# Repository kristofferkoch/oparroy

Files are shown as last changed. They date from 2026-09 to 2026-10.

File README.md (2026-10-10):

# oparroy

A read+write, fault-tolerant ring communication protocol for **extremely
cheap** microcontroller nodes, inspired by the WS2812 single-wire
protocol.

Unlike WS2812's write-only daisy chain, oparroy closes the chain into a
ring so nodes can both send and receive. The physical layer is designed
so that **no single point of failure** — a broken connector (permanent
or intermittent), or a dead/hung microcontroller — partitions the ring:

- The ring is dual: every segment carries two counter-rotating data
  rings with symmetric rebroadcast, so any single fault leaves every
  node reachable ([DESIGN.md §3](DESIGN.md#3-ring-topology-and-bypass)).
- Bypass wiring routes around failed interconnects.
- Each node has a semi-passive hardware watchdog that bypasses the
  node's RX→TX path unless the MCU actively keeps the bypass disabled.
- Status LEDs make faults visually locatable to node and segment
  without instruments.

**Extremely low node cost is the central design principle** (sub-3-NOK
MCU class); every other driver — resilience, repairability,
testability — is achieved subject to it. Supervisor and test
infrastructure, by contrast, may cost freely.

## Hardware direction

- **Node MCU: CH32V003F4P6** — 48 MHz
  RV32EC in TSSOP-20, on-chip comparator routable to timer capture,
  ~$0.14 @4k. Clocked from the factory-trimmed internal HSI — no
  crystal; the ratio-metric PHY makes absolute clock accuracy
  irrelevant. Rationale:
  [docs/mcu-research.md](docs/mcu-research.md);
  extracted part facts: `datasheets/CH32V003/notes/`.
- **Supervisor: RP2040** — its PIO is the re-timing PHY engine and
  golden-reference transceiver; on the test board its PIO also runs as
  a logic analyzer on the instrumented boundary node ([DESIGN.md §6](DESIGN.md#6-test-board)).
- **PHY**: WS2812-compatible duty-coded
  PWM cells with ratio-metric decode at an 800 kbit/s anchor,
  comparator RX + DMA, per-bit cut-through re-timing, positional
  addressing, and the frame gap as a ring-wide vsync latch
  ([DESIGN.md §2](DESIGN.md#2-physical-layer); analysis:
  [docs/phy-analysis.md](docs/phy-analysis.md)).
- **Segment interconnect** ([DESIGN.md §2.1](DESIGN.md#21-ring-power-rail), [§3](DESIGN.md#3-ring-topology-and-bypass)): 2x5-pin IDC
  connectors (2.54 mm box headers on 3M 3365/10 ribbon) carry both
  counter-rotating data rings plus power — a single 3.3 V
  rail that is both the signaling rail and node power, and a raw
  5–18 V rail for payloads with their own buck. On 3M 3365 ribbon,
  segments reach **10 m unamplified**; the 470 Ω TX series resistor,
  not the cable, sets the limit (simulation:
  [docs/cable-reach.md](docs/cable-reach.md)).
- **Node I/O**: potmeter, buttons/matrix, capacitive touch, I2C
  accelerometer, LEDs, buzzer — nodes are smart peripherals serving
  cooked data (Bela/Trill pattern, see
  [docs/bela-lessons.md](docs/bela-lessons.md)).
- **Test board**: 8 ring nodes + supervisor, full fault injection
  (per-segment open/short, per-node power cut, keep-alive cut), everything
  scriptable for hands-off hardware-in-the-loop testing. Doubles as
  the **demonstrator**: some nodes carry human-facing I/O
  (potentiometer, buttons, LEDs, buzzer), each input overridable by
  the supervisor so scripted runs stay hands-off ([DESIGN.md §6](DESIGN.md#6-test-board)).
  4-layer, self-documenting silkscreen. Prototypes assembled by
  **JLCPCB Economic PCBA**; part
  selection is inventory-driven — minimize unique Extended BOM lines.

## Firmware direction

- **Freestanding C++, no standard library** — RAII, placement `new` on
  memory-mapped I/O, `constexpr` config; no exceptions/RTTI/heap.
- Foundation library modeled on **SerenityOS's AK**, landed in
  `firmware/lib/`: `ErrorOr<T>` with `TRY` propagation and fallible
  `try_*` APIs, `VERIFY` with a target failure hook, fixed-capacity
  `StaticVector`/`Span`, and a `StaticArena` slot pool.
- **Ring protocol core** in `firmware/protocol/` — bit cells and
  node/ring forwarding logic ([DESIGN.md §2](DESIGN.md#2-physical-layer)) — proven by **KLEE**
  symbolic-execution harnesses and **libFuzzer** harnesses whose seed
  corpora double as the meson test suite; branch coverage is measured
  on the release build (`scripts/coverage-release`).
- The node pin map is captured in the DSL — 17 of 18 CH32V003 GPIO
  assigned with a budget check — and emits `firmware/node/pins.hpp`
  directly ([DESIGN.md §7](DESIGN.md#7-design-capture-dsl)).
- All of it under the project-owned coding standard:
  [code-std.md](code-std.md) holds the language-independent rules and
  links the per-language standards
  ([code-std-cpp.md](code-std-cpp.md),
  [code-std-python.md](code-std-python.md)) — borrowing from
  JSF AV / MISRA / AUTOSAR / CERT, statically checked
  from the first commit ([DESIGN.md §8](DESIGN.md#8-verification-strategy)).

## Tooling

- **Design capture is code**: the home-rolled Python DSL
  (`src/oparroy/dsl/`, [DESIGN.md §7](DESIGN.md#7-design-capture-dsl)) is the single source of truth —
  an IR with subcircuit composition (ports, port arrays, bundles,
  multipacking, component sockets), a validation pass (limit ranges,
  interval containment, waivers as data), and emitters for KiCad
  netlists, ngspice simulation netlists, and firmware pin headers.
  Footprint assignment and annotation/back-annotation are explicit,
  repeatable stages between capture and pcbnew, so emission is not a
  one-shot export. The parts DB carries assembler-stock status
  (inventory-driven selection), and a `.kicad_pcb` layout property
  checker audits the physical layout (stackup, trace budgets,
  bypass-path copper independence, mechanical contracts). KiCad is
  used for layout only. Learn the DSL from
  [docs/dsl-tutorial.md](docs/dsl-tutorial.md); the API map is
  [docs/dsl-reference.md](docs/dsl-reference.md). Circuit captures live
  in `design/` — the full
  node board is captured (CH32V003 + PHY front-end + charge-pump
  watchdog + status LEDs + segment connectors) — with ngspice benches
  in `circuits/` run via `scripts/sim-run`.
- **Datasheets are extracted, not just stored**: `datasheets/<PART>/`
  holds vendor PDFs plus LLM-readable markdown sidecars (facts,
  per-peripheral notes, quirks) — see `datasheets/README.md`.
- **Meson + ninja** build the firmware ([DESIGN.md §8](DESIGN.md#8-verification-strategy)): one build
  dir per toolchain, freestanding flag set in `meson.build`.
  - host (clang; host objects + LLVM bitcode for KLEE):
    `meson setup build/host --native-file meson/native/clang.ini`
  - CH32V003 (RV32EC objects):
    `meson setup build/rv32ec --cross-file meson/cross/rv32ec.ini`
  - then `meson compile -C build/<dir>`; the reproducibility gate
    `ninja -C build/host check-reproducible` builds every
    configuration twice and compares artifact hashes.
- **nix flake** provides everything non-Python (riscv/arm cross GCC,
  clang 19 + KLEE, AFL++, ngspice, KiCad, uv itself), pinned by
  `flake.lock` — `nix develop` enters the shell (`.envrc` provided for
  direnv users); **uv** owns Python alone (3.14, ruff strict, ty,
  pytest): `uv sync`, then `uv run pytest` / `uv run ruff check` /
  `uv run ty check`.
- **Pre-commit hooks** (`pre-commit install`): clang-format,
  clang-tidy (replaying the host build's `compile_commands.json`), and
  the markdown pipeline
  (mdformat + markdownlint-cli2 + lychee link checks) — cheap checks
  only, ~2 s warm. Hooks are `language: system` against the
  nix-pinned tools, so the flake stays the single tool source.
- **CI** (`.github/workflows/ci.yml`): GitHub Actions runs every gate
  — pytest, firmware host build + unit tests, KLEE proofs, bounded
  fuzz runs, ngspice benches, the rv32ec cross build, the
  reproducibility gate, and the pre-commit suite — inside the nix dev
  shell, so CI exercises byte-identical tools to a laptop.

## Repository layout

| Path | Contents |
| --- | --- |
| `AGENTS.md` | Doc-split and writing conventions for agents |
| `IDEAS.md` | Not-yet-planned ideas (append-only stash) |
| `DESIGN.md` | Settled design decisions + open design questions |
| `KANBAN.md` | Single home for planned work (cards, Next/Backlog) |
| `code-std.md` | Project-owned coding standard: general rules (living) |
| `code-std-cpp.md` | C++ coding standard (living) |
| `code-std-python.md` | Python (DSL) coding standard (living) |
| `README.md` | This file |
| `flake.nix` + `flake.lock` | Pinned dev shell: all non-Python tools ([DESIGN.md §8](DESIGN.md#8-verification-strategy)) |
| `pyproject.toml` + `uv.lock` | Python side: the DSL package (ruff strict, ty, pytest) |
| `src/oparroy/` | Design-capture DSL package (`dsl/`: IR, checks, emitters) |
| `design/` | DSL circuit captures: node board, pin map, parts DB seed |
| `circuits/` | ngspice benches: PHY segment, watchdog, cable reach |
| `tests/` | Python tests (pytest) + golden netlists, `.kicad_pcb` fixtures |
| `meson.build` + `meson/` | Firmware build: flag set, native/cross toolchain files |
| `.envrc` | direnv hook into the flake shell |
| `.pre-commit-config.yaml` | Hook wiring; tools nix-pinned, `language: system` |
| `.github/workflows/` | CI: every gate inside the nix shell |
| `firmware/` | Node/supervisor firmware: foundation lib, ring protocol |
| `scripts/` | Build, sim/proof/fuzz, coverage + pre-commit scripts (sh) |
| `docs/` | Reference documents (research reports, sub-designs); [dsl-tutorial.md](docs/dsl-tutorial.md) + [dsl-reference.md](docs/dsl-reference.md) document the DSL |
| `datasheets/` | Vendor PDFs + extracted markdown sidecars per part |
| `LICENSE` | MIT, copyright 2026 Kristoffer Koch |

Doc conventions follow the IDEAS → KANBAN/DESIGN graduation model:
stray thoughts live in IDEAS.md, planned work in KANBAN.md cards,
settled decisions in DESIGN.md. See
[AGENTS.md §Documentation](AGENTS.md#documentation--the-ideas--kanban--design-split).

## Status

The design-automation pipeline is landed end-to-end: the DSL captures
the full node board, validates it, and emits KiCad and ngspice
netlists, the firmware pin header, and layout constraint skeletons;
simulation benches cover the PHY, the charge-pump watchdog, and cable
reach. On the firmware side the foundation library and the
ring-protocol core are in place under KLEE/fuzz/coverage verification,
and CI runs every gate. No boards exist yet: next up is KiCad layout
of the node board, which unblocks the 8-node test board and the
long-cable bench work. Current work is tracked as cards
in `KANBAN.md`.

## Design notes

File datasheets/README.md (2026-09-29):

# datasheets/

Canonical PDF datasheets and reference manuals for the parts this project
uses, plus LLM-readable sidecar notes. **One directory per part**, e.g.
`datasheets/CH32V003/`:

- `datasheets/<PART>/<PART><doc>-v<ver>.pdf` — the canonical vendor
  documents, version in the filename (e.g.
  `CH32V003/CH32V003DS0-datasheet-v1.8.pdf`).
- `datasheets/<PART>/notes/` — the LLM-readable sidecars. `facts.md` is
  the index and overview (part identity, memory map, electrical quick
  table); each peripheral/topic gets its own file (`opa.md`,
  `timers.md`, `usart-i2c-spi.md`, …) so a task can load only the
  subsystem it touches. `quirks.md` is the errata and tribal-knowledge
  file (issue trackers, wikis, bench findings), one sourced bullet per
  quirk. Facts cite the source document and section (e.g. `(RM §17.2)`).

LLMs read PDFs badly: **read the `notes/` markdown first**; open the PDF
only when the note says the detail wasn't extracted.

## Index

| Part | Role in oparroy | Documents on disk | Notes |
| --- | --- | --- | --- |
| [CH32V003](CH32V003/) | Node MCU — CH32V003F4P6, TSSOP-20 (DESIGN.md §5) | DS0 datasheet v1.8, RM reference manual v1.9, QingKeV2 debug manual v1.0 | [facts](CH32V003/notes/facts.md) + per-peripheral: [opa](CH32V003/notes/opa.md), [timers](CH32V003/notes/timers.md), [dma](CH32V003/notes/dma.md), [adc](CH32V003/notes/adc.md), [gpio-pinout](CH32V003/notes/gpio-pinout.md), [rcc-clocks](CH32V003/notes/rcc-clocks.md), [usart-i2c-spi](CH32V003/notes/usart-i2c-spi.md), [exti-pfic](CH32V003/notes/exti-pfic.md), [sdi-debug](CH32V003/notes/sdi-debug.md), [flash-option-bytes](CH32V003/notes/flash-option-bytes.md), [power-reset](CH32V003/notes/power-reset.md), [quirks](CH32V003/notes/quirks.md) |
| [SN74LVC1G3157](SN74LVC1G3157/) | Ring-A watchdog bypass SPDT analog switch (DESIGN.md §4) | SCES424O (rev. 2025-06) | [facts](SN74LVC1G3157/notes/facts.md) |
| [BAT54S](BAT54S/) | Watchdog charge-pump dual Schottky pair (DESIGN.md §4) | Nexperia BAT54SER v5, TWGMC C727126 | [facts](BAT54S/notes/facts.md) |
| [3M3365](3M3365/) | Candidate segment cable, 28 AWG ribbon (DESIGN.md §3; reach modeling, §9) | 3M TS-0080 v15 | [facts](3M3365/notes/facts.md) |

Not yet vendored: **RP2040** (supervisor MCU, DESIGN.md §5).

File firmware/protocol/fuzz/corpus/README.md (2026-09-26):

# Fuzz seed corpora

Seeds for the libFuzzer harnesses (`firmware/protocol/fuzz/`). Byte
layouts are the harnesses' input grammars — see `fuzz.hpp` for the
event encoding (selector byte `% 5`: 0–2 cell, 3 break, 4 reset; a cell
is selector + period u16 LE + high u16 LE). `scripts/fuzz-run` copies
these into a build-dir work corpus before each run, so the seeds stay
pristine.

## cell/

Raw `(period u16 LE, high u16 LE)` pairs, fed straight to
`decode_cell`.

- `nominal-zero-one` — the two nominal cells (60/19, 60/38 ticks)
- `window-edges` — legality-window boundaries: 43/77 in, 42/78 out,
  high > period
- `tolerance-band` — ±25 % periods (45/60/75) at the 0.32/0.64 ratios

## node/

Prefix: `tele0 tele1 slot_index(u16) slot_bits(u8, mapped to 1+x%16)`,
then events.

- `frame-over-cap` — break, then 2100 nominal cells: past the 2048-bit
  frame cap, the bounded-frame containment case (node.hpp)
- `garbage-cells` — illegal timing, legal cells, break, legal cells
- `reset-mid-frame` — break, cells, brown-out reset, cells, break

## ring/

Prefix: `tele0 tele1 tele2 slot0 slot1 slot2` (slots 0–255, 8 bits
each), then events; a reset event takes one extra node-index byte.

- `three-node-frames` — two clean frames through the chain (echo +
  stamping)
- `faults` — illegal cells, a per-node brown-out, breaks

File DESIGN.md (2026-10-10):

# DESIGN

Settled design decisions, plus §9 for decided-to-be-decided questions
that aren't yet work cards. Sections marked TBD are open.

Settled:

- Project and protocol name: **oparroy**
- License: **MIT**
- Design capture: **home-rolled DSL** (not SKiDL) — owns its IR, emits
  KiCad netlists, constraint checks, firmware headers, simulation netlists
- Test board: **8 ring nodes + 1 supervisor**, **full fault injection**
  (per-segment open/short, per-node power cut, keep-alive cut — all scriptable)
- CI: **local script first** (`test-hw` style target), CI platform
  integration deferred until the board exists
- Firmware language: **freestanding C++ — no standard library**,
  zero-cost abstractions only (RAII, placement new on memory-mapped
  I/O), under an aviation-grade rule set (§8)
- Tool provisioning: **nix flake** for everything non-Python (SDCC/GCC
  toolchains, KLEE/clang, ngspice, KiCad, provers); **uv** for Python
  deps — see §8
- Python tooling: **3.14, uv, ruff (strict), ty, pytest** — package
  scaffold: `src/oparroy/` layout, ruff `ALL` (formatter-conflicts
  off), ty, pytest wired via pre-commit
- MCU: node = **[CH32V003F4P6](datasheets/CH32V003/)** (TSSOP-20),
  supervisor = **RP2040**; toolchains GCC riscv + GCC arm, clang host
  build retained for KLEE (§8)
- Node time base: **internal HSI RC, no crystal** — §5
- PHY: ratio-metric duty-coded PWM, 800 kbit/s anchor, comparator
  RX + DMA, per-bit cut-through re-timing — §2
- Bypass topology: **counter-rotating dual ring, symmetric
  rebroadcast** — RX source select via the OPA's second positive
  input, no per-node parts — §3
- PCBA: prototypes assembled by **JLCPCB** (Economic PCBA); fallback
  for unstocked parts is PCBWay partial-turnkey (§6)
- Firmware build system: **Meson + ninja** — §8
- Ring power rail: **3.3 V, one rail** for signaling and node power;
  regulation is per-payload, never per-node — §2.1

## 1. Overview

oparroy is a single-wire, self-clocked ring protocol inspired by WS2812.
Closing the daisy chain into a ring makes communication bidirectional
(read + write) and provides the substrate for fault tolerance.

Design drivers, in priority order:

1. **Node cost — the central design principle.** Extremely low per-node
   cost outranks every other concern; all other drivers are achieved
   *subject to* it (sub-3-NOK MCU class, minimal external parts). Every
   feature that adds per-node parts or board area must argue for its
   existence against this driver. Note the asymmetry: **supervisor and
   test infrastructure may cost freely** — cost discipline applies to
   the replicated node, not to the one-off tooling around it.
1. **Resilience**: no single connector failure (permanent or intermittent)
   or single MCU failure partitions the ring.
1. **Repairability**: when a fault does occur, it is visually locatable
   to node and segment without instruments (§4.1).
1. **Testability**: hands-off hardware-in-the-loop testing from day one.

## 2. Physical layer

Decided (against the CH32V003's peripherals; full analysis:
[docs/phy-analysis.md](docs/phy-analysis.md)). 800 kbit/s confirmed by
simulation (measured block below); bench confirmation lands with the
test board. Break length is a firmware/timer decision: the analog side
owes only fast, chatter-free settling to idle, which tb_fault shows.

- **Line coding: WS2812-style duty-coded PWM cells with ratio-metric
  decode.** Fixed bit cell, high-then-low; `0` = short high pulse
  (~1/3 cell, T0H ≈ 0.40 µs), `1` = long high pulse (~2/3 cell,
  T1H ≈ 0.80 µs). The spec is the *ratio* — high-time/period against
  the cell midpoint — not absolute times: the coding tolerates ~±25 %
  node-clock error, so HSI-only nodes (±2.2 % worst case, no crystal —
  §5) sit an order of magnitude inside budget. The wire signal stays
  WS2812-compatible, so COTS decoders, test gear, and RP2040 PIO
  reference code work unmodified.
- **Bit rate: 800 kbit/s anchor** (1.25 µs cell = 60 timer ticks at
  48 MHz; capture resolution 20.8 ns). The rate is a free parameter —
  the ceiling is comparator response and cable reach (§9), not the
  timers — but at 800 k the OPA (12 MHz GBW, 7.7 V/µs) is nowhere near
  the bottleneck and COTS WS2812 tooling applies. Frame/latch marker:
  line-low break, ≥ 50 µs baseline (WS2812's reset is the upper
  reference; MCU nodes may go shorter once bench confirms — the
  vsync semantics below ride on the break either way).
- **Signaling: 3.3 V single-ended**, push-pull at VDD per segment,
  idle low. RX threshold = VDD/2 divider on an OPA negative input. The
  OPA has no documented hysteresis: glitch rejection comes from the
  TIM2 input digital filter (ICxF) plus ratio-decode margins, not
  analog feedback. Simulation confirmed this
  (`circuits/phy-segment/tb_noise.cir`): zero spurious rxout edges
  under ringing (lseg ≤ 1 µH × cseg ≤ 470 pF) and under ±250 mV-class
  capacitive crosstalk at ±13 mV comparator offset; worst high-time
  error ~1.2 ns against a ≥ 100 ns decode-margin budget. ICxF fCK_INT
  N=8 is free insurance (its ~167 ns delay is edge-symmetric and
  cancels in the ratio). The feedback-resistor fallback (OPO = PD4)
  stays unpopulated.
- **RX path:** OPA comparator routed *internally* to TIM2 CH1 — no
  GPIO spent on the comparator output. TIM2 PWM-input mode (CH1+CH2
  pair, hardware counter reset) captures per-bit period and high-time;
  DMA channels 5/7 stream captures into an SRAM ring buffer. Per-bit
  ISRs are ruled out: 60 cycles/bit at 800 kbit/s leaves nothing after
  PFIC entry; decode runs per burst, amortized ~10 cycles/bit
  ([opa.md](datasheets/CH32V003/notes/opa.md),
  [timers.md](datasheets/CH32V003/notes/timers.md),
  [dma.md](datasheets/CH32V003/notes/dma.md)).
- **TX path:** TIM1 PWM + DMA streaming compare values against a fixed
  cell period (fallback: SPI + DMA with bit-to-symbol encoding, which
  frees TIM1 for application PWM per §5's I/O complement). TIM1's
  brake input is reserved as a hardware TX-kill for the watchdog /
  babbling-idiot story (§3, §4).
- **Re-timing: per-bit cut-through regeneration, slot rewrite on the
  fly** (user decision, superseding the initial store-and-forward
  baseline). Every node decodes upstream bits and
  re-synthesizes the TX waveform from its own timer — snapped to
  nominal T0H/T1H — after a small, bounded pipeline delay, so decode
  jitter is per-hop (~one timer tick), never cumulative
  (*regeneration*, not topology, is what bounds jitter; WS2812 chains
  reshape too, but oparroy's re-timing is explicit and
  firmware-controlled, not entrusted to a chip's internal reshaping).
  A node streams the frame through bit-by-bit and only intercepts its
  own slot — reads command bits, substitutes telemetry bits — as it
  passes: the WS2812/EtherCAT shape. Ring circulation ≈ one frame
  time + N×pipeline delay (~0.6 ms, ~1.6 kHz full-ring update at
  8 nodes) instead of N×frame-time. **Buffering policy**:
  the pipeline is deep enough to relax the CPU budget — order 8–16
  cells, processed in bursts off DMA half-transfer interrupts — and
  hard-bounded so ring DMA buffers stay **≤ 256 B of the 2 KB SRAM**,
  statically allocated (≈8 B/cell RX + 2 B/cell TX): some buffering to
  buy CPU slack, never enough to become a RAM problem. The node
  locates its slot by counting bits from the frame gap (position =
  address, below); ENUM frames are pre-sized so stamping is a slot
  rewrite, never an insertion. The trade: per-hop frame filtering is
  lost — a corrupt frame is already downstream before a CRC could
  reject it — so containment moves to illegal-cell detection (period
  outside 0.9–1.6 µs ⇒ stop regenerating, force the line idle), a
  **frame-length cap** (a stream of legal cells past `frame_max_bits`
  = 2048 without a break — 2× the pre-sized ENUM maximum — is a
  babbling idiot too, contained the same way: Mute until the next
  break), the TIM1-brake TX-kill and hardware bypass (§3, §4), and
  supervisor-side CRC/sequence checks (feeds the §9 intermittent-fault
  policy).
  Fallback rung: if the per-bit loop doesn't close timing on-target,
  degrade to store-and-forward (decided with measurements on-target).
  Closure discipline: the supervisor is the only frame originator and
  drainer; echo mismatch ⇒ fault.
- **Addressing: positional, discovered — no solder bridges, no
  provisioning step.** Position in the ring *is* the address. The
  supervisor enumerates with one circulation of an ENUM frame that
  each node stamps with its factory 96-bit UNIID (ESIG — see
  [flash-option-bytes.md](datasheets/CH32V003/notes/flash-option-bytes.md))
  plus a type byte; the position ↔ UNIID map rebuilds automatically
  when a node is
  replaced. Solder-bridge IDs (Trill-style, bela-lessons §2) lose on
  pin budget (≥2 GPIO on an 18-GPIO part) and per-node parts — the §1
  cost driver. One firmware image, personality by type byte in flash
  (node firmware).
- **Telemetry: slotted in the circulating frame, not polled.** Each
  node writes its own slot as the frame passes, with inputs sampled at
  the vsync latch (below) — synchronous sampling in the ring's
  timebase (bela-lessons §1), deterministic latency (~1.6 kHz
  full-ring update at 8 nodes, cut-through — see re-timing above), no
  poll round-trips. The frame sequence counter is the timestamp.
  Frame format detail is node-firmware scope (KANBAN.md).
- **Ring-wide latch: the frame gap is a vsync — WS2812's "global
  shutter" in both directions**. The line-low break that marks frame
  start drives two synchronized actions at every node:
  (a) **apply** the command outputs received in the previous frame,
  from a double buffer — LED/buzzer state never changes mid-frame, so
  patterns don't tear across positions; (b) **sample** inputs, so
  every telemetry slot in frame k holds values from the same latch
  instant L_k, tagged by the frame sequence counter. Effect is
  simultaneous even though data delivery is positional: the break
  itself propagates around the ring, so inter-node skew = accumulated
  pipeline delay, ≤ N×depth ≈ 160 µs at the baseline — bounded,
  sub-perceptual for human interface, tight enough for correlated
  multi-node sensing (button chords, gestures, accelerometer arrays).
  Cost: one double-buffer stage per node (bytes, inside the 256 B
  ring-buffer cap); the break detector already exists to reset the bit
  counter, so the latch event is free.

Rejected codings (analysis doc §1): pulse-distance (data-dependent
slot timing, longer average cell); Manchester (doubles the transition
rate, no benefit for comparator RX); USART-async (two HSI ends bust
the async sampling budget — kept as fallback only if bench testing
kills the comparator-RX path).

Measured (ngspice — benches in `circuits/phy-segment/`, models in
`circuits/lib/ch32v003.spi`):

- **Decode margins (tb_decode)** — 24 combos (segment capacitance
  47 pF–1 nF × comparator offset ±13 mV × bypass/inserted switch
  path): every cell lands ≥ 178 ns from the decode midpoint at the
  TIM2 Schmitt slice (≥ 144 ns at the pessimistic VDD/2 slice), period
  1245–1253 ns everywhere — a healthy segment never trips the
  0.9–1.6 µs illegal-cell detector. Margins are flat vs capacitance
  (±4 ns across 47 pF→1 nF) and vs offset (< 4 ns): the binding effect
  is the comparator's 7.7 V/µs slew (~230 ns edge-symmetric delay,
  ~50 ns pattern-dependent), not drive strength vs segment C.
- **No analog hysteresis (tb_noise)** — see the signaling bullet
  above; zero spurious edges under ringing and 250 mV-class crosstalk.
- **Connector faults (tb_fault)** — short to GND/VCC parks the line
  static and chatter-free (idle-high is distinguishable from a
  dead-quiet segment). An open segment requires the MCU's internal
  weak pull-down (35–55 kΩ, DS0 §3.3.9 T3-16) enabled on the OPA
  inputs: the severed line then parks idle-low, comparator static
  ≤ 33 µs even at 1 nF (~12× inside the 2-frame flip budget, §3), at
  zero BOM cost. Without it the line floats to a leakage-decided state
  — static in sim, but a chatter hazard on real silicon.

Open: drive strength vs cable (§9),
exact frame format (node firmware).

### 2.1 Ring power rail

Decided: **the ring distributes a single 3.3 V rail** — it is both the
signaling rail (the §2 push-pull, VDD/2-threshold PHY) and node power.
No per-node regulator: the CH32V003 runs 2.7–5.5 V straight off the
rail ([power-reset.md](datasheets/CH32V003/notes/power-reset.md)), and
every §4 watchdog / §2 PHY bench plus the §7 protection sizing is
already characterized at 3.3 V.

- **5 V rail rejected**: the MCU could run at 5 V directly, but
  nothing else follows. The always-on SN74LVC1G3157 at 5 V VCC has
  VIH ≈ 0.7×VDD = 3.5 V — unreachable from a 3.3 V sel driver (§4) — and
  §5's sensor payloads (I2C accelerometer class, 3.6 V max) need 3.3 V
  regardless, so 5 V moves regulation onto the sensor instead of
  removing it. WS2812 *electrical* compatibility isn't bought either: a
  5 V-powered strip wants VIH ≈ 3.5 V, and §6 already rules WS2812 LEDs
  off the board (Standard-PCBA tier); the wire stays WS2812-compatible
  in coding regardless (§2).
- **Power headroom**: node loads are tens of mA (MCU ~4 mA at 48 MHz,
  GPIO-driven plain LEDs, small piezo), and the power loop is driven as
  a loop (§3), so a 3.3 V rail holds ample margin against the MCU's
  2.7 V floor. A future power-hungry payload carries its own regulator —
  a per-payload cost, not a per-node tax (§1). If the loop drop budget
  ever busts — check lands with the §9 cable numbers, worst case a
  connector break turning the loop into a long spur — the fix is
  supervisor-side power injection at a second tap (§1: supervisors may
  cost freely), not a higher rail.
- **Unregulated payload rail**: alongside 3.3 V, the bus carries a raw
  **5–18 V** rail for payloads that outgrow tens of mA — anything with
  its own buck converter. The 18 V cap comes from
  the cheap-buck ceiling: commodity buck regulators typically spec
  ≤ 20 V max input. Node power and ring logic never touch it — nodes
  stay on 3.3 V, regulation stays per-payload (§1) — it is plain
  copper on the bus (§3 pinout) until a payload uses it.

## 3. Ring topology and bypass

Decided: **counter-rotating dual ring with symmetric rebroadcast.**
Every segment carries two data wires in the same cable/connector: ring
A (primary, clockwise) and ring B (counter-rotating). The requirement
holds with no per-node parts: **single fault ⇒ every node stays
reachable** (FDDI wrap property).

Mechanism:

- The supervisor originates the same frame on both rings and drains
  both; echo mismatch on either drain ⇒ fault (§2's closure discipline,
  applied per direction).
- Every node decodes its selected source and regenerates the stream
  onto **both** TX directions (TX_A + TX_B: two TIM1 channels with
  identical compare values), so ring B always carries a live copy of the
  same logical frame, hop-delayed. Positional addressing, slot rewrite,
  and the vsync latch (§2) are source-invariant — a node that flips
  direction counts slots from the break exactly as before; no
  per-direction ENUM.
- **RX source select is firmware policy, not hardware.** The OPA's two
  positive inputs (OPP0 = PA2 = ring A, OPP1 = PD7 = ring B; `OPA_PSEL`
  in `R32_EXTEN_CTR` — [opa.md](datasheets/CH32V003/notes/opa.md)) mux the
  comparator. No edges for > 2 frame times ⇒ flip source. Firmware is
  safe here because the node at the receiving end of a dead segment is
  alive by definition — a dead MCU is §4's case. Flap/hysteresis policy
  for intermittent opens is open (§9). **The internal weak pull-down
  stays enabled on both OPP inputs** (§2 measured block, tb_fault): it
  parks a severed segment idle-low and chatter-free, which the flip
  policy depends on.

Per-node cost: no parts; +1 wire +1 connector contact per segment; +2
GPIO per node (PD7 as RX_B — already an OPP input — plus one TX_B pin).
The §5 pin budget lands at ~16–17 of 18, verified at pin-map time
(§7 pin map). Electrically neutral for the PHY: every driver still
sees exactly one segment, so the §2 measured baseline and the §9
reach budget are unchanged by the topology.

Segment connector (supersedes the earlier 6-pin pinout): **two 10-pin
2.54 mm 2x5 IDC box headers per node** on
10-way 1.27 mm-pitch 28 AWG ribbon (3M 3365/10 or generic UL2651) —
the AVR-ISP shape, the deepest-stocked IDC system there is. Pricing
fetched 2026-09-29 (LCSC @100): header C22385222 $0.069 + cable-side
socket C8373 $0.084 → **$0.31 of connectors per node**; the 2.0 mm
and 1.27 mm-pitch IDC systems run 2–4× that on thin stock, and the
1.27 mm system has no 28 AWG cable at all (0.635 mm ribbon is
30 AWG, a third off the power budget) — §1's cost driver outranks
the larger footprint. The dual-row IDC straddle lands odd conductors
in one row and even in the other, so the conductor order

```
UNREG, GND, 3V3, GND, A, GND, B, GND, 3V3, GND
```

makes row 2 a solid ground row with every conductor ground-flanked —
the datasheet G-S-G configuration behind the reach model's
102 Ω / 47.5 pF/m numbers
([docs/cable-reach.md](docs/cable-reach.md)) —
and quarantines UNREG at the cable edge, away from both data wires.
Both faces share one pinout by wire identity: pin 5 is the ring-A
data wire, pin 7 the ring-B one, whichever face you look at; naming
stays node-centric (RX_A/TX_A = this node's ring-A
receive/transmit). Doubled 3V3 plus five grounds drops the power
loop to ~0.15 Ω/m, stretching the broken-loop power budget
(cable-reach §5) from 5.8 m to ~12 m at 10 mA nodes — past the 10 m
signal reach, so power stops binding segment length. Power enters a
node from both directions — the power loop above. The header is **SMD
on the board's back side**, hand-soldered post-PCBA:
JLCPCB places the front only — single-side SMT keeps the Economic
tier (§6) — and the front stays flat as the enclosure-wall mount
face. No stocked SMD box header carries anchor pegs or hold-downs, so
the gull-wing joints alone take the mating load — unmating is
in-plane shear, the gentle direction — and the through-hole variant
(C2977596) stays in the parts DB note as the high-pull-force
fallback. The cable-side socket vise-presses onto the ribbon, no
crimp tooling. Friction fit is deliberate: connectors remain the
fragile element under test (§6) — the shroud only keys against
reverse insertion.

Interaction with §4: the watchdog SPDT bypass stays, on ring A only —
dual ring demotes it from sole defense to second layer. A dead MCU
breaks ring B at that node (TX_B floats) while ring A bypasses it; a
connector break severs both rings at one point and every node is still
served from the live side. (The power loop already survives single
breaks for free — it is driven as a loop, not a direction. The
asymmetry the second data wire fixes is the data ring's
directionality.)

Failure modes, answered:

- Permanent open at a connector — both rings severed at one point;
  nodes past the break flip to the live direction; all nodes reachable.
- Intermittent open at a connector — direction-flap policy deferred
  (§9); the hardware substrate is now settled.
- Short to GND / VCC on a segment — treated as an open of that wire;
  the other direction covers. Rail shorts are the CI-board eFuse's
  scope (§7).
- Dead MCU (no clock, outputs floating) — §4 charge-pump bypass on
  ring A; ring B lost at that node, coverage by A.
- Hung MCU — same path: keep-alive stops, bypass engages.
- MCU transmitting garbage (babbling idiot) — §2 containment
  (illegal-cell stop, frame-length cap), TIM1 brake kills both TX
  channels, §4 bypass follows.

Rejected:

- **Per-node switch only** — a connector open darkens every node
  downstream of the break back to the supervisor's drain; fails §1
  driver 2 outright.
- **Skip-one wires (N→N+2)** — whole-connector-yank coverage needs
  physically separate skip assemblies leaping a node: 2× pitch halves
  the §9 reach budget on the engaged path, and avoiding permanent
  double drive-loading costs +1 SPDT per node. Sharing the connector
  instead cuts coverage to single-contact faults. Equal-or-less
  coverage for worse mechanics.

## 4. Node watchdog / bypass

Decided: an **edge-sensitive charge pump** holds a normally-on analog
switch open; when the MCU stops strobing, the switch relaxes closed
and RX→TX bypass engages. The window-watchdog supervisor
IC candidate is rejected on cost/inventory (below). Both candidates
live as standalone subcircuits with ngspice testbenches:

- `circuits/watchdog-chargepump/` — **chosen**.
  [BAT54S](datasheets/BAT54S/)-class dual Schottky pump (Cp=22n,
  Rs=220, Cs=10n, Rb=47k, τ=0.47 ms) driven by a 20 kHz MCU keep-alive;
  its `sel` output drives the switch select.
- `circuits/watchdog-supervisor/` — the rejected TPS3430-class window
  watchdog, kept as the quantified record of what the money would have
  bought.

Switch: [SN74LVC1G3157](datasheets/SN74LVC1G3157/) SPDT (facts in
[its notes](datasheets/SN74LVC1G3157/notes/facts.md)). COM = downstream,
B1 = upstream — bypass is the default, sel low —, B2 = node TX. The
node's RX tap stays connected in bypass: a dead node keeps listening
(listen-only); bypass cuts TX only.

Requirement (unchanged): RX→TX bypass is the **default state**; the MCU
must actively deassert it. Semi-passive — no firmware in the bypass
path itself.

Measured (ngspice, swept across both select-threshold edges
0.99/2.31 V):

- **Engage speed**: bypass closes ~0.5 ms after the last keep-alive
  edge — link-level, sub-frame. Bit-level bypass switching is neither
  needed nor achievable with this class of circuit.
- **Missed-pulse tolerance**: one dropped 50 µs keep-alive cycle droops
  sel only to ~2.5 V, still above the 2.31 V VIH edge — no spurious
  engage.
- **Glitch immunity**: the Rs·Cp input filter makes narrow (100 ns)
  glitches transfer nothing.
- **Accepted hazard**: a µs-wide *periodic* waveform is a false
  keep-alive (sel ~2.9 V with a Hi-Z dead driver, ~1.3 V mid-band with
  a stuck-low driver). Anchored in tb_glitch phase 2.

Window vs timeout — the window property is traded away on a
cost/inventory argument (JLCPCB, 2026-09-26): window-watchdog ICs are
not inventory-viable — TPS3430 $1.50 VSON-10, TPS3435 ≥$2.50, MAX6369
$1.92, each more than the CH32V003 itself ($0.29, §1) — and the stocked
timeout-only supervisors (TPS3823 $0.25, STWD100 $0.37) add nothing
over discrete. Candidate A is ~$0.01 of Basic-class discretes. What the
money would have bought, measured in candidate B's benches: one dropped
strobe costs only a bounded 1.51 ms self-recovering bypass blip (A
instead tolerates the drop silently and engages ~0.5 ms late when
strobes stop for real; B's timeout engage is 1.49 ms after the last
strobe); an early edge latches the fault ~0.2 µs after the offending
edge, vs A's analog droop; a 3.3 kHz glitch train after MCU death
cannot service the window (the first glitch resets the ramp unjudged —
engage slips to 1.70 ms — every later glitch is an early edge that
re-sets the latch); and the select output snaps rail-to-rail, with no
10 ns/V input-rate violation.

Known spec violation, accepted: A's slow sel ramp breaks the switch's
10 ns/V input-rate spec ([SCES424O](datasheets/SN74LVC1G3157/) §5.4) —
≤500 µA ΔICC while dwelling ~0.4 ms in the 0.99–2.31 V band, once per
fault event. A 74LVC1G17 Schmitt buffer on sel fixes it for one
Extended BOM line if the bench disagrees. Insurance on the node
board: a **DNP 74LVC1G17 footprint in the sel path, bridged by a
fitted 0 Ω** — the fix becomes a resistor swap, not a respin.

Power: bypass switch + watchdog run from the **always-on ring rail**,
not the per-node switchable rail — the 1G3157 has no Ioff /
partial-power-down spec. Shaped §3; still constrains the §6 test
board.

### 4.1 Fault detection and serviceability

Fault tolerance keeps the ring alive; detection and repairability make
failures findable and fixable. Per-node status LEDs, sized for field
diagnosis without instruments:

- **Power LED** — passive, lit whenever the node is powered
- **Working LED** — MCU-driven heartbeat; off (or blinking an error
  pattern) when firmware is hung/dead. Pairs with the watchdog: bypass
  engaged ⇒ working LED dark ⇒ the failed node is visually obvious
- **Per-connector status LED** — one per ring connector, showing link
  status on that segment (activity / no-signal / error, encoding TBD).
  Points repair at the exact failed segment or connector, which is the
  whole point of the bypass wiring.

Hardware note: per-connector status should ideally be driven by the
link/PHY hardware (comparator activity detect) rather than firmware
alone, so LEDs still tell the truth when the MCU is dead. GPIO/LED
count feeds the MCU requirements in §5 and the test board in §6 — on
the board these LEDs double as test observability, but they are a
product feature, not board-only debug.

Status-LED delivery: the four status LEDs are **reverse-mount 1206
parts on the front** (XINGLIGHT XL-3216-FB series — parts DB),
emitting through routed holes in the PCB to the **back — the
connector side, where a viewer stands**. The LED pads stay on the
front, so single-sided assembly and the flat enclosure-wall face are
untouched, and the back's copper set stays exactly the two segment
connectors (§7 checklist). One series covers all four positions; the
per-connector link pair is the 570 nm yellow-green (the series' 525 nm
true green has Vf 3.4 V, undrivable from a 3.3 V GPIO), and the
working LED is the 588 nm yellow so the roles stay visually distinct —
red = power, yellow = working, green = link. Layout-checkable (§7):
each status LED sits over its routed hole.

Per-connector LED drive: **firmware-driven**, confirmed against the
hardware-activity ideal above — the watchdog plus working LED already
flag a dead node, and the CI board observes truth through
the §6 supervisor taps, so per-node activity hardware doesn't survive
the §1 cost driver. The two connector LEDs merge onto **one GPIO as
an antiparallel pair** with a shared series R: pin high lights
upstream, low lights downstream, Hi-Z dark, a kHz toggle lights both
at half brightness. That frees PC1 (an FT pin) and one resistor; the
cost is firmware encoding complexity and the loss of independent
steady states. The activity/no-signal/error encoding itself stays
firmware scope (the §4.1 TBD above).

## 5. MCU platform

Decided:

- **Node MCU: [CH32V003F4P6](datasheets/CH32V003/)** (WCH RV32EC @
  48 MHz, **TSSOP-20**) — ~$0.29 at prototype qty, $0.137 @4k (LCSC
  **C5187096**, JLCPCB Extended, ~9k in stock 2026-09-26). Its OPA
  comparator routes to TIM2 CH1 capture; two capture-capable timers +
  DMA. TSSOP-20 over the
  QFN-20 variant (F4U6): avoids JLCPCB's per-board X-ray fee for
  leadless packages and stays hand-reworkable.
- **Supervisor MCU: RP2040** ($0.70–1.00, LCSC **C2040**, JLCPCB
  Extended) — PIO is the re-timing PHY engine and golden-reference
  transceiver for characterizing the CH32V003's analog-RX path; also
  ring supervisor on the test board (§6). Unavoidably QFN-56, so the
  X-ray fee is budgeted. Explicitly **not** the node part at ~3× the
  node budget (§1).
- **Toolchains**: GCC riscv (ch32v003fun-class SDK) for the node, GCC
  arm for the supervisor; clang/LLVM-bitcode host build retained for
  KLEE (§8). All provisioned by the nix flake.
- **Node time base** (§2 analysis): **internal HSI 24 MHz RC + PLL ×2
  = 48 MHz — no crystal on the node.** HSI is
  factory-trimmed to −1.2/+1.6 % over 0–70 °C ([CH32V003
  datasheet](https://akizukidenshi.com/goodsaffix/CH32V003.pdf)). The
  duty-coded, self-clocked PHY with per-node re-timing makes absolute
  accuracy irrelevant: decode is ratiometric on a single clock per hop
  (§2), and the worst case moves a 0.4 µs pulse by ±6.4 ns against a
  ±150 ns tolerance window. The debug UART stays within async tolerance
  (±1.6 % ≪ the usual ±2–3 % budget). Any ring-wide slotted/timestamped
  scheme must resync from data edges, never from free-running node
  clocks. HSE pins stay unconnected (the HSE clock-security fallback to
  HSI is moot); the supervisor RP2040 keeps its 12 MHz crystal for USB
  — supervisors may cost freely (§1).
- **8051-class ruled out**: the freestanding-C++ decision (§8) needs
  GCC/clang and SDCC is C-only. The recalled sub-3-NOK Silabs part —
  most plausibly EFM8BB1 at launch-era pricing, per
  [docs/mcu-research.md](docs/mcu-research.md) —
  is excluded on toolchain grounds, not price. No current Silabs
  listing is sub-3-NOK anyway.

Full comparison remains in
[docs/mcu-research.md](docs/mcu-research.md).

Requirements the chosen part satisfies (retained as the checklist for
any future node-MCU revisit):

- Analog comparator (RX) — or a PIO/programmable engine that makes a
  comparator unnecessary
- Timer with capture or PCA for edge timing (RX decode / TX encode)
- Fast enough core/peripherals for the target bit rate
- Flash/RAM budget TBD
- Toolchain: GCC/clang (freestanding C++, §8) — 8051/SDCC excluded

Node I/O complement — peripherals a node may carry, and what each
demands of the MCU:

- Inputs: potentiometer (ADC), button / button matrix (GPIO, matrix
  scan pins), capacitive touch (dedicated capsense peripheral, or
  comparator/timer-based implementation), I2C accelerometer (I2C
  controller or bit-bang)
- Outputs: LED (GPIO/PWM), buzzer (timer/PWM)

So the MCU checklist grows by: ADC, enough GPIO for a small key matrix,
capsense capability (dedicated or constructible from the comparator +
timers), I2C, and a spare PWM channel. The test board (§6) should
populate nodes with a mix of these so protocol testing carries real
application traffic.

## 6. Test board

Decided: **8 ring nodes + 1 supervisor** (supervisor = MCU or USB bridge
that can power-cycle nodes, inject faults, collect debug UART).
**Full fault injection**: per-segment open/short switches, per-node
power cut, keep-alive cut — everything scriptable from the supervisor so
test runs are fully hands-off (design below).

Dual role: the CI board is also the **demonstrator**. Beyond hands-off
test runs, it must show the protocol to a human — so a subset of nodes
carries real human-facing I/O from the §5
complement: at minimum a potentiometer and buttons on input nodes,
LEDs and a buzzer on output nodes, populated as a mix so test traffic
*is* application traffic (§5). Properties this exploits for demos: the
§4.1 status LEDs already narrate ring health visually, and the §2
vsync latch makes multi-node LED/buzzer patterns tear-free — a fault
injection live on stage (yank a connector, watch the bypass LEDs and
the ring carry on) is the demo. Constraint: the human I/O must never
be required for operation — every input is also drivable/readable
scriptably, so the hands-off CI role is unaffected by a knob being in
the wrong position. Board-design consequence: human inputs are
**overridable from the supervisor** (the fault-injection paragraph
below): the potentiometer's wiper goes through an analog mux so the
supervisor can substitute its own filtered-PWM voltage during scripted
runs (same injection pattern as the fault muxes), and buttons parallel
a supervisor-driven N-FET.

Board fabrication: the CI/test board is **4-layer** — the
fault-injection muxes and per-node debug plumbing want the routing
room, and the §1 cost driver doesn't apply to test infrastructure.
Node-board stackup settled separately (§9): **2-layer, 0.8 mm**.

Prototype assembly: **JLCPCB Economic PCBA** for the first prototype
boards. Fab order: the **CI/test board fabs first** — its eight node
tiles are the first bench articles for the §2/§4 claims — and the
standalone node board follows, assembled at the 2-board minimum as the
production-form proof (single-sided assembly, back-side hand-soldered
headers, pogo programming flow). Research + inventory snapshot:
[docs/pcba-research.md](docs/pcba-research.md).
Facts that shape board design:

- **Min 2 assembled boards**, ~$10 fixed (setup + stencil) +
  **$3.07 per unique Extended BOM line** — all of CH32V003, RP2040, and
  the 74LVC/TS5A-class switches are Extended, so the design rule is
  **minimize unique BOM lines** and reuse parts across nodes.
- **Single-side SMT** to stay on the Economic tier; actual WS2812-class
  LEDs are "Standard PCBA only" (moisture bake) and would force the
  pricier tier — use plain LEDs on the board.
- QFN packages incur a per-board X-ray fee — TSSOP CH32V003 (§5);
  RP2040 is unavoidably QFN.
- PCB fab minimum is 5 even when assembling 2 — spare blanks come free.
- VOEC-registered: Norwegian VAT settled at checkout.
- Fallback for anything JLCPCB can't stock: **PCBWay partial-turnkey**
  (1-pc MOQ, true consignment), at 2–4× the price.
- Third-party population is acceptable: consignment and Extended-line
  fees are just money — what the design avoids is hand-soldering
  jellybean passives ourselves at volume.

Consequence: **part selection is
inventory-driven** — prefer parts the assembler stocks; anything
outside their library costs setup fees or hand-soldering. The DSL
parts DB tracks assembler-stock status (§7).

Node programming: nodes program **post-SMT over SWIO** — the
CH32V003's single-wire debug on PD1 is the only way in (no factory
bootloader; [quirks.md](datasheets/CH32V003/notes/quirks.md)
§Debug), and PD1 is the pin map's one hard reservation. Flow:
JLCPCB places the front; each board then lands on a **pogo jig**
(the bela-lessons first-class deliverable) where a **WCH-LinkE** —
the official probe; clones hit flash-unlock walls (quirks) —
flashes the single node image plus the personality type byte where
a board carries one. **The programmer powers the board**: brick
recovery is a power cycle through reset (quirks), so the jig's 3V3
comes from the WCH-LinkE, never the ring, and the board exposes a
**SWIO + GND + 3V3 pad strip** for it (§7 checklist). Positional
addressing (§2) means **zero per-node provisioning** — one image,
no serial numbers burned; the factory UNIID (ESIG) is read at flash
time and logged against the handwritten unit serial (§7 checklist).
The back-side connectors go on *after* programming — the bela
rework-stage ordering.

CI flash fan-out: **the flash-busy time of all eight nodes must
overlap** — programming time dominates test time, and the
floor per node is silicon flash-busy, not transport: 256 fast pages
(64 B) at 2.4–3.1 ms each ≈ 0.8 s
([flash-option-bytes.md](datasheets/CH32V003/notes/flash-option-bytes.md)).
Serializing that busy time — one shared probe doing node after node —
puts ~7 s of dead time in front of test runs that themselves measure
in milliseconds. Mechanism: **one PIO SWIO channel through an analog
mux to the selected node**, pipelined round-robin — stream a page
(16 words ≈ 0.7 ms of wire), kick the page program, switch the mux to
the next node while the first is busy; poll the status registers
round-robin. Legal because SWIO has
no inter-packet timing requirement: the protocol is host-paced
(minichlink already inserts USB-scale gaps between packets), so the
mux may dwell anywhere between transactions. One channel keeps
~4 nodes' flash pipelines full (3 ms busy vs 0.7 ms wire per page);
with 8 nodes the wire becomes the bottleneck and total flash time is
≈ max(8 × 0.2 s transport, 0.8 s busy) ≈ 1.6 s — the requirement is
met, with QDM fast mode (§2.2) in reserve. The mux is a low-Ron
analog switch (74LVC1G3157-class, already a stocked BOM line;
analog switches are bidirectional, which half-duplex SWIO needs);
deselected nodes idle SWIO high on a **per-node 10 kΩ pull-up,
target side of each mux port**: the 003's internal weak pull-up
(35–55 kΩ, 45 typ — DS0 §3.3.9) holds DC with ~5× margin
against mux off-leakage (~6 µA worst case → 0.33 V droop) but is
soft against capacitive coupling from the seven other switching
channels, and the external resistor also covers the 002/4/5/6
variants whose SWIO mandates one (quirks). Bus-keepers rejected:
they hold *last state* on a line that must idle *high*, power up
undefined, and this rig power-cycles nodes for brick recovery — a
keeper latched low wedges SWIO. A second pull-up (4.7–10 kΩ) sits
on the mux **common port**: rise time after a turnaround release is
RC on the common net, and at HSI/3 = 8 MHz (T = 125 ns) the
internal pull-up alone (τ ≈ 1.4 µs on ~30 pF) is an order too slow.
Bench-verify on the CI board: deselected-port SDI false-trigger —
a node so triggered drives its own disconnected stub, harmless
until reselected, recovered by session-start resync. PIO bitbang
proven by PicoRVD (quirks §Debug). Per-node power switching (brick recovery)
is required regardless. Live SWIO debugging is single-target by
nature: the mux simply **parks on the DUT** for the GDB session, no
switching overhead. Caveat for live-ring debugging: halting a node
starves its watchdog, so the §4 bypass engages around it — the
designated debug DUT below carries a defeat bit for exactly this.
Programmer tooling (minichlink-class) joins the flake with the node
firmware.

CI control plane: **all slow control and observe on the CI board is
one long daisy-chained shift register with a global latch/capture
clock** — 74HC595-class stages for control (mux enables, per-node
power switches, fault-injection switches, human-I/O overrides),
74HC165-class stages for observe. A handful of RP2040 pins (clock,
data out, data in, latch) drives the whole board; chain length scales
with the fault-injection complement instead of consuming GPIO, and
every actuator is one bit — no I2C addressing, no bus contention,
fully deterministic.

Fault-injection design
([docs/instrumented-ci.md](docs/instrumented-ci.md)
— the transform list the transform machinery encodes and the CI
capture consumes): every segment wire gets a scriptable four-state
injector — pass / open / short-to-GND / short-to-3V3 — built from
three SN74LVC1G3157 SPDTs (one series break, two 470 Ω-legged
shunts; every latched bit pattern is electrically safe, no
interlocks), placed once per segment at each tile's downstream
connector, plus the same on the supervisor's originator port.
**Per-node power cut** is a P-FET high-side switch (AO3401A-class)
splitting the tile's 3.3 V into an always domain (bypass switch,
injectors — the §4 no-Ioff constraint) and a node domain (MCU, status
LEDs, payload); it doubles as the brick-recovery power cycle. The
**clock-kill fault class does not exist on this node** — HSI-only
(§5), NRST option-byte-disabled
([quirks](datasheets/CH32V003/notes/quirks.md)) — and resolves to the
power cut (dead), a series switch on the keep-alive strobe (hung:
watchdog bypass engages with the MCU alive and observable), and SWIO
halt on the debug DUT. Control rides the shift-register plane under
one invariant: **bit 0 = the plain-board state on every control
bit**, so the reset-state load is all-zeros — these levels are the
reset-state equivalence proof's inputs. Human-I/O overrides: the pot
wiper through a 3157 substitution mux (supervisor drives filtered
PWM), buttons paralleled by 2N7002-class N-FETs (optocoupler
rejected — the board is common-ground). The boundary node's four
taps (`opa_p`, `TX_A#b` post-injector, comparator-out, working-LED) carry **no series
resistors** — stimulus drives against the segment's existing 470 Ω —
and the watchdog-defeat bit is a 3157 shunt forcing `sel` high. The
doc also carries the residual register (every reset-state difference
from the plain node, enumerated and budgeted) and the bench-verify
list.

Board power and host link: one **USB-C receptacle** is both the power
inlet and the supervisor's host link. 5 V in — CC sink pull-downs
only, no PD negotiation; the load (8 tiles at tens of mA each, §2.1,
plus RP2040 and the scan plane) sits trivially inside baseline USB-C
delivery — and an on-board **3.3 V regulator** feeds the ring rail
(§2.1) and all board logic. The receptacle's D+/D− wire to the
RP2040's USB (it keeps its 12 MHz crystal for exactly this, §5), so
one cable is power, host channel, and debug transport uplink.
Regulator and connector are inventory-driven picks (§6); the per-node
power-cut switches of the fault complement sit between the rail and
each tile — P-FET high-side per tile (above), so the bypass switch
and the fault injectors stay on the always-on rail per §4 while the
MCU domain is cut.

Open: runtime debug transport (UART per node? shared bus?). The
segment connector is settled (§3) — and stays deliberately fragile:
it is the failure mode under test.

Instrumented boundary node: the ring node adjacent to the supervisor —
first/last, where the supervisor closes the ring — is **extra wired to
the RP2040**. Both of its ring segments (the node's RX
tap and its TX output) land on RP2040 GPIOs, so the supervisor's PIO
runs as a **logic analyzer / bus debugger on that node**: at the
125 MHz sysclock that's 8 ns resolution (~156 samples per 800 kbit/s
cell), DMA'd into the RP2040's 264 KB SRAM for deep captures. The
supervisor sees exactly what the node saw vs what it re-emitted —
per-hop latency, re-timing fidelity, decode errors under fault
injection — which is the measurement half of its golden-reference role
(§5). The same PIO pins can drive crafted/glitch waveforms back as
stimulus. Two further taps: the node's comparator-output GPIO and its
working-LED line (§4.1), so observation stays truthful even when the
node's MCU misbehaves. Taps must be short stubs — probing must not
deform the segment under observation (a §7 layout-checker contract).
The §1 cost driver doesn't apply: this is test infrastructure.

The instrumented boundary node is also the **designated debug DUT**:
a live SWIO session parks the flash mux on it, and the two segment
taps are already on RP2040 PIO, so one node gets the full loop — GDB
halt/single-step *and* logic-analyzer capture of
what it received vs re-emitted, with the same pins able to inject
crafted stimulus at its RX while stepping. To make halting useful it
carries a **watchdog-defeat bit** in the shift-register chain: while
set, an override holds the §4 bypass switch in the node-active
position, so a halted or single-stepped node stays electrically in
the ring instead of being bypassed on watchdog timeout. Default is
watchdog-in-charge; the defeat bit is a debug-session tool.

Silkscreen documentation: the CI board is self-documenting at the
bench — **connector pinout voltages and test-point labels printed on
the board** (e.g. `3V3`, `5V`, `GND`, `TP12 ring-seg-3`), so probing
never requires the schematic open on a second screen. Layout-checkable
(§7): every connector and test point carries a silkscreen label.

## 7. Design-capture DSL

Decided: **home-rolled DSL** (not SKiDL). The DSL is the single source
of truth for:

- Schematic (→ KiCad netlist; layout done in KiCad)
- Constraint / property checks
- Firmware pin and register headers
- Analog simulation netlists (ngspice)

Rationale: owning the IR makes multi-target codegen and property
verification straightforward; a KiCad/SKiDL-format emitter is just one
backend. Package scaffold: see §8 tooling.

DSL shape (from the initial design interrogation):

- **Separable, pretty-printable IR.** The IR is a real data structure,
  dumpable and diffable; its printed form is for humans — it does not
  need to round-trip back into DSL source.
- **Checks run as a validation pass** over the finished IR
  (capture → check → emit), not at connection time. Structural
  invariants (unique references, a pin on at most one net) still raise
  at construction — they are not checks but what makes the IR
  well-formed.
- **Instrumentation is a transform pass, not a second capture.**
  Test-board instrumentation (series inserts, shunts, taps,
  substitutions) is declared as data and applied by
  `src/oparroy/dsl/transform.py` to the hierarchical capture — after
  instantiation, before check — flattening each matched tile instance
  in place and rewriting its nets. Every part and net the engine
  creates carries a `Provenance(transform, base)` tag that survives
  flattening and renaming — the input of the **reset-state equivalence
  proof** (`src/oparroy/dsl/equivalence.py`):
  `check_equivalent(base, instrumented, plan, …)` proves the
  instrumented board in reset state reduces to the plain board (series
  elements to wires, shunts absent, taps high-impedance, the anti-drift
  bijection over base parts and nets), per tile and composed upward,
  with every residual enumerated as data against a budget citation —
  electrical magnitudes from the parts DB (`PartRecord.residuals`),
  geometry residuals emitted as layout-checker obligations
  (`docs/instrumentation-equivalence.md` §2/§4, Q3/Q5 settled).
- **Plain function-call API, HDL-instantiation flavor.** Named
  connections, no operator overloading, no implicit global circuit.
  Sugar only if the call style proves tedious in use.
- **References are explicit instance names.** A part's refdes is given
  at capture (`circuit.part("Rs", ...)`), like an HDL instance name —
  no auto-assignment scrambling references when a part is inserted
  (SKiDL's pain), so pcbnew's ref-matched netlist import stays stable
  across source edits.
- **KiCad library integration is mandatory.** Symbol/footprint
  references validate against KiCad's actual libraries (provisioned via
  the flake) — without that, pcbnew ingest can't be trusted.
- **Lean on KiCad's own code where possible**. When both the DSL and
  KiCad can do a job, drive KiCad rather than re-implement it: every
  line we don't write is a line we don't maintain against KiCad
  releases. KiCad is the merge engine between generated and hand-edited
  artifacts — ref-matched netlist import for connectivity, Board
  Setup's Import Settings from Another Board for constraints; the DSL
  emits and audits. The Import Settings step is itself scripted:
  `src/oparroy/dsl/pcb_merge.py` drives the same merge through
  pcbnew's SWIG API, run in the project venv — the dev shell puts
  nixpkgs' pcbnew on `PYTHONPATH` and the project pins the same
  Python 3.14 it is built for
  (`python -m design.node_board --apply DIR`), keeping layout and
  GUI-authored project state intact while re-imposing the emitted
  constraints.
- **The pipeline is not one-way**. Between capture and pcbnew sit
  **footprint assignment** and **annotation** as explicit, repeatable
  stages — annotation re-runs during layout so numbering
  ends up reflecting physical placement (KiCad's geographic annotation
  is the norm). Capture names stay the stable identity (the explicit
  instance names above); annotation maps them to placed refdes, and the
  DSL accepts pcbnew's back-annotation rather than treating emission as
  a one-shot export.
- **Footprints default per part class, overridable per instance**.
  Declaring a footprint at every instantiation is too verbose: a part
  class carries its default footprint in the capture, and later stages
  (assignment, the parts DB) may override. ICs bind
  their package at capture — the package decides which pins physically
  exist, so it is never a late-stage decision. The checker's
  missing-footprint error applies to the **post-assignment** IR: class
  defaults resolve during capture, so a part reaching `check` without a
  footprint has neither default nor assignment — that is the error.
- **Typed jellybean parts, strings for the rest**. Common passives and
  transistors get real Python classes — `Resistor`, `Capacitor`,
  `Diode`, `Nfet`, `Pnp`, `Npn`, … — so the type checker and
  autocomplete do the work stringly-typed declarations can't.
  Classes accrete as captures need them (YAGNI — no speculative zoo).
  One-off parts stay string-declared, but **declared in one place and
  instantiated elsewhere**: declaration is data, instantiation is
  wiring. Instantiation is **keyword-only**: positional arguments are
  a pin-swap factory (the BAT54S x/sel swap, found in review, is the
  proof). Pin names are the keyword names —
  `Diode(*, cathode=sel_net, anode=x_net)` — so construction *is* the
  wiring: no separate `connect` call for typed parts, and the type
  checker and autocomplete cover declaration and connection alike. Sole
  exception: `Resistor` and `Capacitor` may take their value
  positionally — one unpolarized value carries no orientation risk;
  `CapPol` and anything else with direction-sensitive pins, never.
  Enforced with `*` in the class signatures.
- **Multi-unit packages mirror KiCad's unit model**. KiCad encodes
  multi-unit symbols as `<Name>_<unit>_<style>` subsymbols: unit 0 =
  pins/graphics common to all units, style 1 =
  normal body / 2 = De Morgan (graphics-only for us), and each unit's
  pins carry **physical package pin numbers** — the LM2902 is four
  op-amp units plus a separate power unit; the BAT54ADW is four diode
  units whose *shared anode pins appear in several units*. eeschema
  places units independently (U1A, U1B, …; unplaced units don't
  exist), and the netlist export flattens to refdes + physical pin
  numbers — pcbnew never sees units. The DSL mirrors this: `Symbol`
  preserves unit structure (see below), a placed part instantiates a
  **unit subset** (default: all — today's behavior), unplaced units
  materialize no pins so the unconnected-pin
  check stays clean, and a physical pin shared by several placed units
  sits on one net (KiCad ERC's own rule) — structural in the IR,
  where a physical pin number is one `Pin` that can sit on only one
  net. Package-as-one-part
  stays right for units used as a single element: the BAT54S series
  pair is a single unit in KiCad's own library, which is exactly the
  `Bat54s` typed-class choice.
- **Computed values carry slack**. A computed value (divider ratio,
  filter corner) is a spec — target plus tolerance — not a number: the
  emitter resolves it to a real part from a stocked
  bin (the VDD/2 divider draws from the 10k bin), never an unsourcable
  irrational value. Resolution runs against the parts DB's value
  bins (§6 inventory-driven selection). `Part.value` widens from a
  string to a value-spec type when this lands — a designed change to a
  public constructor parameter, not a patch (KANBAN.md).
- **Captures live in a new `design/` tree.** `circuits/` keeps benches
  and device models until the bench DUTs are ported and the DUT `.cir`
  files retire.
- **Human-review rendering:** a Graphviz dot dump is the minimal first
  view (ugly, but a start); the goal is abstraction-level block views
  in the Verilog-debugger sense — prior-art survey:
  [docs/prior-art-schematic-gen.md](docs/prior-art-schematic-gen.md)
  — borrow the layout engine (grandalf first, ELK fallback), build
  only the view extraction; the views are open work (KANBAN.md).

Landed: the DSL core in `src/oparroy/dsl/` — `ir.py`
(parts/pins/nets/circuit + pretty-print), `check.py`
(validation pass: connectivity, footprint existence and symbol
footprint-filter match, power-driver rules with KiCad's own
power-symbol convention — a `power:`-library pin marks its net
driven), `kicad_emit.py` (the
s-expression `.net` pcbnew imports; byte-identical emission —
sorted iteration, content-derived UUID tstamps, no dates or paths;
power symbols excluded like eeschema's own export),
`dot.py` (Graphviz dump), `kicadlib.py` + `sexpr.py` (KiCad 10 library
access, `extends`-aware), `parts.py` (typed jellybean parts —
`Resistor`/`Capacitor`/`Bat54s`, keyword-only pin wiring at
construction, class-default footprints per bin). Proven by
`design/watchdog_chargepump.py`:
the §4 charge pump captured on typed parts against the
nix-provisioned KiCad
libraries, golden netlist in `tests/golden/` (byte-identical across
the typed-parts migration), 92 pytest cases green.
Not yet proven: a real pcbnew netlist *import* — the golden format is
pinned, the ingest is exercised when the first board enters layout.
The KiCad application joins the flake, pinned to the library version
the DSL validates against, so pcbnew ingest and layout cannot drift
from the validated libraries.

Subcircuit composition: hierarchy is capture-time structure,
**flattening is a pass** — `subcircuit.py`
(`Subcircuit` base), `Circuit.port` (a net marked as interface, exempt
from the dangling-net checks), `Circuit.instance` (captures the child
per instance and binds every port by keyword; unknown or unconnected
ports raise at capture), `Circuit.flatten` (instance names prefix part
references and internal nets — `WD1/Rs`, `WD1/x` — while port nets
merge into the net their instance bound; explicit names at every level
keep refdes stable across source edits). `/` is the hierarchy path
separator and is rejected in instance names, part references, and net
names alike; unbound (top-level) ports keep their interface flag
through flattening, so the dangling-net exemption survives the pass.
Hierarchy survives flattening
as metadata: `Part.path` feeds real `sheetpath`s in the KiCad netlist
with content-derived tstamps — the channelization hook. Check and the
emitters flatten implicitly and report hierarchical paths. The §4
watchdog is the first subcircuit (`design/watchdog_chargepump.py`); the
8-instance proving case runs in `tests/test_dsl_subcircuit.py`.
Remainder of that split: multipacking and component sockets (below),
connection sugar (KANBAN.md).

Port arrays and bundles: the interface scales past scalar ports.
`Circuit.port_array` declares a width-fixed vector
(`led[0]`…`led[7]`) bound element-wise at instantiation — a width
mismatch raises at capture (button matrices, LED arrays); elements may
also bind individually by name. `Circuit.bundle` groups *existing*
nets under member names — the §3 connector pinout as one connectable
unit. Members name wires, not node functions (`a` is the ring-A data
wire on pin 5 of both faces), so two faces join member-to-member; the
power nets alias into both faces' bundles, and a port reached through
two groups must resolve to one parent net — conflicting bindings
raise. `BundleConnector` (parts.py) is the connector block: the
member→pin-number mapping is class data, and `pin_map` values widen to
tuples for a member owning several pins (the §3 ground row and the
doubled 3V3). `design/segment.py` carries the §3 pinout
(`segment_ports`) and the connector block itself (part and footprint
settled in §3). Both group forms expand to scalar port bindings at
instantiation: flattening, checks, and emitters see plain nets only.
One checker fix rode along: footprint filters match against
the full `Lib:Name` as well as the bare name, so KiCad's lib-qualified
filters (`Connector*:*_1x??_*`) work.

ngspice emitter: `spice_emit.py` (`emit_spice`) is the
simulation-netlist backend over the flat IR. It emits the DUT
as a `.subckt` with ports in declaration order; stimulus and `.meas`
assertions stay in the external bench decks (`circuits/**/tb_*.cir`) —
the DSL emits the circuit, benches drive it — so a capture whose ports
match a hand-written `circuits/` interface drops into the same benches
unmodified, and either capture can drive the run while the remaining
DUTs are ported over. Spice bindings are ad hoc until the parts DB
owns them: a symbol-keyed table (R/C two-pin primitives, the BAT54S
series-pair expansion) plus caller-passed `.model` definitions, a
part's value naming its model as in a hand-written deck. Emission is
byte-identical like the KiCad emitter's, hierarchy flattens implicitly
(ngspice
accepts `/` in element and node names verbatim), and element names
keep the ref, gaining a kind-letter prefix only when flattening hid it
(`WD1/Rs` → `RWD1/Rs`). Proven by `design/watchdog_chargepump.py --spice`: the emitted `wd_chargepump` passes all three §4 benches
(`tb_engage`, `tb_missed_pulse`, `tb_glitch`) through
`scripts/sim-run` — the DUT-port equivalence pattern, rehearsed.

Port limit ranges and waivers: typed ports carry electrical limit
**ranges** — `Circuit.port(..., source=…, sink=…)`
taking `Limits(voltage=Interval, current=…)` — and the validation pass
checks **interval containment** over every net's declared endpoints: a
sink's acceptable range must cover the connected source's output range
(a PolymorphicBlocks steal), so tolerance stackup becomes checkable
data. Voltage is checked when declared, current when both
sides carry it; an undeclared side is no data, not a finding. Grouping
per net — not per binding — covers sibling instances wired
port-to-port through a plain net, the common board-level case. The
check runs over the instance hierarchy before flattening, so findings
and waivers address hierarchical paths (`WD1/ka`). **Waivers are
capture data** — `Circuit.waive(check, path, reason=…)`, never
comment-style suppression: a waived error degrades to a `WAIVED`
finding (visible in the report, not erased, not blocking) and a waiver
matching nothing warns as stale. A waiver declared inside a
subcircuit is relative to it; instantiation prefixes the path.
`design/watchdog_chargepump.py` declares the first contracts (`ka`
accepts 0..3.6 V, `sel` drives 0..3.3 V). Still open: the bypass-path
single-fault and watchdog default-state checks, which need the
board-level captures they inspect, and pin/part-level ranges (today
only ports carry them — port arrays and bundles not included).

Parts DB: `parts_db.py` holds one record per part — LCSC number,
JLCPCB Basic/Extended tier, a stock snapshot with its as-of date and
source, the KiCad symbol/footprint pair, the spice model binding, and
the datasheet pointer into
[`datasheets/`](datasheets/README.md) — the §6
inventory-driven-selection view as data. Selection is **constraint
filtering over the table**, not lookup: a `PartFilter` is refinement
data (kind, tier, area bounds, an allowed-footprint set, exclusions, a
required part, an in-stock constraint) composing conjunctively, so
assembler-stock status is a column *and* a checkable constraint.
`PartsDb.bind` turns a record into a typed part class — the record
owns symbol/value/footprint — so captures draw their bins from the
table (`design/parts_db.py` binds `R0603`/`C0603`; capture-specific
parts bind at the capture site) instead of re-declaring footprint
pairs per capture, retiring the earlier ad-hoc bin classes.
`PartsDb.check_stock` is the freshness audit: stale snapshots,
never-queried parts, unverified tiers, and stock-outs surface as
warnings (`python -m design.parts_db`); the per-capture
unsourcable-part gate is open work. Stock numbers are as-of-dated
snapshots with provenance, never live data — re-query JLCPCB before
ordering. Full emitter-side resolution against value bins —
the solve pass — is open work (KANBAN.md).

Firmware pin maps: `pinmap.py` — pins are requested by function
(`gpio.request("keepalive")`), pads bind late as
refinement data (`gpio.bind(keepalive="PD3")`), and the one
authoritative table feeds both consumers: `emit_pin_header` (the
freestanding-C++ header — `constexpr` pads plus peripheral-channel
constants, [code-std-cpp.md#6-constants-and-configuration](code-std-cpp.md#6-constants-and-configuration) style) and `check_pin_map` (the §5
GPIO-budget check: the bound pad carries every used signal, one
function per pad, reservations honored, requests + reservations inside
the chip's GPIO count). Chip data (`Chip`/`Pad`) is datasheet-derived —
the CH32V003F4P6 table covers the default alternates only (DS0 §2.1,
[gpio-pinout.md](datasheets/CH32V003/notes/gpio-pinout.md)); AFIO
remaps are refinement room, added when a binding needs one.
`design/node_pins.py` is the node table — 16 function requests plus the
SWIO reservation = **17 of
18 GPIO, PC7 spare**, verifying §3's "~16–17 of 18" at pin-map time as
§3 predicted — and `firmware/node/pins.hpp` is the generated
header, byte-pinned by `tests/golden/node-pins.hpp` and compile-proven
on both toolchains (`firmware/node/pins.cpp`: host clang + rv32ec
GCC). Regeneration stays a manual step
(`python -m design.node_pins > firmware/node/pins.hpp`); meson
`custom_target()` wiring lands with the first consumer (the node
firmware). The table's third consumer is the node capture itself:
`design/node.py` binds its MCU pads from `capture().assignments`
rather than hardcoding them — the drift that
motivated it (the capture had keepalive on PC4 and the LEDs on
PC7/PC5/PC6 against the table's PD3/PD0/PC0/PC1 — a fabbed board
would have kept the watchdog permanently strobed-out and dark) is
the proof that two pad tables cannot coexist.

Node board and the capture→layout stages: the ring node is captured
in `design/node.py` — CH32V003F4P6
(`design/ch32v003.py`: pins keyword-only by port name, power pins
required, the rest reported unconnected by name via the typed-part
optional-pins hook), the PHY front-end (`design/phy_frontend.py`:
SN74LVC1G3157 bypass with the RX tap on B1, VDD/2 threshold divider
from the 10k bin, ring-B protected RX/TX, 470 Ω + TVS footprint per
§7-checklist terminal, the §2 hysteresis fallback carried as DNP), the
§4 charge pump, the §4.1 status LEDs (power / working / per-connector),
an SWIO test pad, and the two §3 segment connectors. TIM1_BKIN (PC2)
is wired to the watchdog's `sel` — bypass engaging brakes both TX
channels (§2). `Node` is a subcircuit: the node board captures it
directly, and the §6 test board tiles it eight times. Between capture
and pcbnew sit the two stages this section promised: `assign.py`
(footprint overrides
as JSON data on top of the class-default bins, now shared in
`design/bins.py`) and `annotate.py` (capture names → board refdes;
prior annotations survive source edits; comp tstamps are keyed on the
new `Part.identity`, not the refdes, so pcbnew keeps matching by
timestamp across re-annotation; `annotation_from_pcb` folds KiCad's
geographic renumbering back out of `.kicad_pcb`). Typed parts grew
`Led` and `TvsDiode`. Golden: `tests/golden/oparroy-node.net`. Not yet
proven: real pcbnew ingest and the back-annotation join against a real
layout (the caveat above) — first layout is human work, and the §9
node-board stackup question settles at quote time.

Multipacking and component sockets: the multi-unit model above lands.
kicadlib preserves KiCad's unit
structure — `Symbol.common_pins` (unit 0, present in every placed
unit) and `Symbol.units`; `pins` stays the all-units view and
`Symbol.pins_for_units` resolves a subset. A `MultiUnitPart` subclass
declares the placed subset with typed per-unit pin names
(`unit_pins`); construction places but wires nothing — units wire
individually through typed handles (`connect(net, u1.unit(1).anode)`,
`Part.unit` returning a `UnitHandle`) or pack into component sockets.
The shared physical pin is one `Pin` in the IR, so the one-net rule is
structural: rewiring it to the same net (once per sharing unit) is a
no-op, a second net raises at capture, and a packing that would split
a shared pin across two nets raises at flatten. A component socket
(`Circuit.socket`, a `SocketSpec` subclass naming its protocol pins
and a standalone `default` typed part) lets a subcircuit declare it
needs a *part*, not just nets: the capture wires the protocol pin
handles like part pins, and the instantiating parent directs the
packing — `instance(..., D1=u1.unit(3))` packs the socket into one
unit of a parent-placed package (one unit satisfies one socket),
`D1=SomeDiode` directs the standalone part class, and an unbound
socket materializes as the protocol's default part under the instance
path (`CL0/D1`) at flattening. The subcircuit stays package-agnostic.
`Bat54adw`, `Diode`, and `DiodeSocket` are the first typed parts on
the model; proven in `tests/test_dsl_units.py` and
`tests/test_dsl_sockets.py` against a stub quad diode mirroring the
BAT54ADW shared-anode pinout, plus real-library unit-structure tests
(BAT54ADW, CD4066BE's switch+power units). **Caveat: packing across
the ring-A/B redundancy boundary reintroduces a single point of
failure** — two rings' diodes in one package share its pins and its
silicon. The DSL makes packing the
parent's directed, review-visible choice; it does not (yet) forbid a
cross-boundary pack — that is a checker-level rule for the capture
that needs it, not a socket-mechanism restriction.

Circuit organization: **functional circuits live in their own
subcircuit files** (e.g. the RC pulse watchdog is one file, one unit),
composed into boards — not drawn flat into a board schematic.
Each subcircuit carries **simulation unit tests**: standalone ngspice
testbenches asserting its contract (for the watchdog: bypass engages
within T of pulse loss, stays engaged through a single missed pulse,
does not false-trigger on line glitches). Subcircuits are the unit of
reuse, review, and test; boards are composition. Part selection note:
every part chosen must exist in the prototype assembler's inventory
(§6) — the DSL's parts DB should carry assembler-stock status per part
so constraint checks (§8) can flag unsourcable parts early.

Layout property checking: the constraint role extends to the
**physical layout**. Layout is drawn in KiCad, but the DSL *audits*
it: parse the `.kicad_pcb` (S-expressions, friendly to Python) and
assert layout-level properties the schematic can't express, e.g.:

- **Bypass-path independence**: the watchdog bypass route must not
  share copper/vias with node logic between RX and TX — the physical
  embodiment of "no firmware in the bypass path" (§4)
- **Placement contracts**: per-connector status LED adjacent to its
  connector (§4.1); supervisor/debug connectors at board edge
- **Mechanical contracts**: rounded board corners (non-painful
  handling — checkable as min corner radius on the edge-cuts layer),
  mounting holes for standoffs/"legs" with correct keepouts
- **Electrical geometry**: net-class width/clearance compliance, max
  segment trace length against the cable-reach budget (§9), keepout
  respect
- KiCad's own DRC stays authoritative for manufacturability; the DSL
  checker covers *project semantics* DRC can't know about. The DSL can
  also *push* constraints the other way — emitting the stackup and
  keepouts into the `.kicad_pcb` and the net classes and board
  minimums into the `.kicad_pro`, so the layout tool guides the human
  toward compliance before the audit runs.

Board-level checklist (grows as boards are designed; each item is
either a layout-checker assertion or a subcircuit):

- Power LED (§4.1) — every board, no exceptions
- **Power input protection: eFuse/crowbar subcircuit** — its own
  subcircuit file with sim unit tests (crowbar trip point, reverse
  polarity behavior, eFuse current limit) per the §7 organization
  above. Scope: **CI/test board only** — future single-node cards stay
  cheap and carry no such protection (central cost driver, §1).
- **I/O terminal protection: series R + optional TVS**: every terminal
  that leaves the board gets a series resistor near the µC pin, sized
  against the CH32V003 injection
  current (±4 mA/pin, Σ ±20 mA, DS0 §3.2 T3-1) — 470 Ω on ring
  TX/RX (470 Ω × 50 pF ≈ 24 ns edge softening, far inside the §2
  decode margins) and on user-facing outputs (7 mA into a shorted
  pin, inside the ±8 mA spec'd drive), 1 kΩ on buttons, ADC sources
  ≤ 10 kΩ total including the series R
  ([adc.md](datasheets/CH32V003/notes/adc.md), T3-24). The R also
  caps phantom-power injection into a powered-down node (the §4/§6
  power-cut fault). Prefer FT pins (PC1/PC2/PC5/PC6) for any
  terminal that can see 5 V. Plus a **TVS footprint per external
  terminal**, wired connector → TVS → R → µC so the R limits what
  the internal clamp diodes absorb after the TVS clamps.
  Low-capacitance bidirectional ESD parts (tens of pF, VRWM
  ≥ 3.3 V) — not nF-class power-rail TVS. **Population rule: the CI
  board ships fully populated** — test the superset, since DNP
  strictly removes load and a passing CI with TVS covers the bare
  variant; leave one CI node DNP to cover populated↔unpopulated
  segments in the same run. Production nodes may ship DNP. The
  standalone node boards ship populated as well — they are the first
  bench articles for the §2/§4 claims. The power-rail TVS pairs with
  the eFuse/crowbar above and is *not* optional. Layout-checkable
  (§7): TVS adjacent to its connector, R between TVS and µC pin.
- Rounded corners, mounting holes for legs (layout checker, above)
- **Single-sided SMT; connectors on the back**: every PCBA-placed part
  sits on the front — single-side SMT keeps the JLCPCB Economic tier
  (§6) — and only the two §3 segment connectors sit on the back, SMD,
  hand-soldered post-PCBA. The front is the flat enclosure-wall mount
  face; the §4.1 status LEDs shine through routed PCB holes to the
  back (§4.1), visible from the connector side — the enclosure owes
  nothing. Layout-checkable: the
  B.Cu footprint set is exactly the segment connectors, and each
  status LED sits over its routed hole.
- **Programming strip: SWIO + GND + 3V3 pads** (§6): the pogo-jig
  target for post-SMT programming — three pads together at a board
  edge, 3V3 driven by the programmer, never the ring.
  Layout-checkable: presence, adjacency, edge placement. Geometry:
  **2.54 mm pitch, three 1.5×1.5 mm pads, on a short board edge** —
  the pogo jig consumes exactly this.
- **Board identification on silkscreen**: every PCB carries project
  name (`oparroy`), PCB name, author name, date, and version number —
  checkable as required text fields on the fab/
  silkscreen layers. Version number ties the physical board to a git
  tag so HIL results are attributable to an exact design revision.
- **Handwritten serial-number field**: every PCB carries a white
  silkscreen area (hatched/filled box, sized for a fine marker) to
  write a per-unit serial number by hand at bring-up — the git-tag
  version identifies the *design*, the handwritten serial identifies
  the *physical unit* when several boards of the same revision are on
  the bench. Layout-checkable: a silkscreen box of minimum area, kept
  clear of pads and other silkscreen text.

Landed: the layout checker in `src/oparroy/dsl/` —
`kicad_pcb.py` (a tolerant `.kicad_pcb` parser on top of `sexpr`:
stackup, net classes, footprints/pads, copper (segments, arcs, vias),
board
outline, silkscreen texts/rects, zones), `layout_check.py`
(`LayoutRules` as the contract, `check_layout` reporting batched
`Issue`s like the schematic pass: copper-layer count and thickness,
net-class width/via compliance, per-net trace-length budgets, min
corner radius with collinear-junction exemption, required silkscreen
board-ID fields, serial-box area, mounting-hole count and keepout
coverage, footprint adjacency and presence, the §4 bypass-path
independence check — pad whitelisting plus copper-geometry
independence: no bypass segment, arc, or via may touch another net's
copper on a shared layer — and the §7 terminal-protection placement
contracts (TVS adjacent to its connector, series R straddling the
exposed net near the protected logic; `terminal_protection_rules`
derives them from the capture, which names the parts, so the contract
survives KiCad's geographic renumbering)), and `pcb_emit.py` (a
byte-identical skeleton emitter pushing constraints into pcbnew
pre-audit; round-trips through the parser). Proven against
`tests/fixtures/board_pass.kicad_pcb` and calibrated against
`boards/node/`, where the bypass chain clears all other copper by the
class clearance (0.3 mm) and all four terminal chains meet the
placement contract. Not yet
landed: serial
box pad/silkscreen clearance (waits on footprint rotation modeling)
and
the channelization hook (per-instance layout replication over the
subcircuit sheetpaths — waits for a hierarchical board).

Skeleton emitter, KiCad 10 shape (verified headless against KiCad
10.0.6 — `kicad-cli pcb upgrade`/`pcb drc`, exercised in
`tests/test_dsl_kicad10.py`): KiCad 10 rejects `net_class` in
`.kicad_pcb` `(setup)`, so the skeleton is a **pair** —
`pcb_emit.emit_pcb` writes the `.kicad_pcb` (stackup, keepouts, net
list; still format 20240108, pcbnew upgrades on open) and
`pcb_emit.emit_project` writes the `.kicad_pro` (net classes in
`net_settings.classes`, net→class membership in
`net_settings.netclass_assignments` — the key is
`netclass_assignments`, the `class_patterns` spelling is silently
ignored; board minimums in `board.design_settings.rules`).
DRC-enforcement facts the design relies on: per-class clearance and
the board minimums are DRC-enforced headless; net-class track width
is a routing default only, so per-net width/via contracts stay with
the layout checker, which now reads classes from the project
(`kicad_pro.parse_project`, `check_layout(..., project=...)`) with
board-file classes as fallback. Quirks, both documented where the
code hits them: stackup paste layers must not carry
thickness/material (the upgrader mangles them into dielectrics), and
a class clearance ≤ 0.25 mm is enforced but the violation text
reports an empty constraint name (above 0.25 mm it cites the class).
The node board's spec is `design/node_board.py`; the emitted pair
lives in `boards/node/`.

## 8. Verification strategy

Layers: DSL property checks (schematic **and physical layout**, §7),
**subcircuit simulation unit tests**
(ngspice testbenches per subcircuit file, §7), analog simulation of
integrated circuits, on-target
hardware-in-the-loop testing with fault injection. **Local script first**
(a `test-hw` style target run manually against the bench board); CI
platform integration (self-hosted runner attached to the board) deferred
until the board exists.

Firmware: **rigorous and statically checked from the start** — strict
compiler warnings, static analysis, and symbolic execution (KLEE-class
provers) wired in from the first firmware commit,
not retrofitted. Language: **freestanding C++, no standard library**
(`-ffreestanding -nostdlib`, no exceptions, no RTTI, no heap unless
explicitly carved out) — the zero-cost subset used deliberately: RAII
for resource/lock ownership, placement `new` on memory-mapped I/O for
type-safe register blocks, `constexpr` for pin/config tables, templates
where they erase per-node cost. **Exceptions policy** (retained:
`-fno-exceptions`): the unwinder + personality routine + unwind tables
cost ~10–40 KB flash — more than the entire
16 KB CH32V003; `throw` allocates (heap or emergency buffer) in a
system that otherwise never allocates; unwinding time is
data-dependent, breaking the bounded-latency story the PHY needs and
the WCET analysis aviation-grade rule sets demand (JSF AV bans
exceptions outright); and landing-pad control flow taxes KLEE and
coverage. Replacement idiom: `expected<T,E>`-style result types +
`[[nodiscard]]` — error paths stay visible in the type system and free
at runtime. Revisit only if the node MCU grows by an order of
magnitude.

Foundation library: our freestanding "unstandard" library is **modeled
on SerenityOS's AK** — the library that proved you can
have modern C++ ergonomics without exceptions:

- **`ErrorOr<T>`** as the universal fallible return type; our
  `expected<T,E>` idiom above *is* this
- **Fallible APIs everywhere allocation can fail** — AK's
  `try_append`/`try_emplace` returning `Error` instead of throwing or
  aborting; on oparroy nodes most storage is static, but the
  convention still rules: anything that *can* fail returns, it never
  traps silently
- **`TRY(...)` propagation macro** (AK's) as the exception-free error
  plumbing — reads like exceptions, compiles to branches
- **Ownership types** (AK's `OwnPtr`/`NonnullOwnPtr`/`FixedArray`)
  adapted to static arenas instead of a heap
- **`VERIFY`/assert macros** with a project-defined failure hook —
  on a node, assertion failure policy ties into the watchdog story
  (§4): deliberate bypass-engage, not a hung loop

Not copied from AK: anything POSIX-flavored, hidden allocation,
infinite growth. The node library's spine is fixed-capacity containers
with explicit `try_` growth. Landed in `firmware/lib/`: `Span`,
`irange`, `StaticVector`, `VERIFY`; `Error`/`ErrorOr<T>`/
`ErrorOr<void>` + `TRY` (`GrowthResult` subsumed — `try_*` now returns
`ErrorOr<void>`), `StaticArena` + `ArenaPtr` ownership over static
slot pools, `UNREACHABLE`, VERIFY's target personality
(`-DOPARROY_TARGET` → `lib::verify_failed`, the §4 wiring point — the
node firmware's hook definition lands with the node firmware), `lib::move`
(`utility.hpp` — AK's spelling; `<utility>` stays outside the
freestanding header set, [code-std-cpp.md#1-language-and-toolchain](code-std-cpp.md#1-language-and-toolchain)), and the StaticVector → `Span`
implicit conversion (the `std::vector` → `std::span` analog, AK's
`Vector`/`operator Span` shape).
`Error` is a bare `enum class` code, not AK's string-carrying class —
widen to a payload-carrying class the day an error needs more than a
code. Rule set: **project-owned** — `code-std.md` at the repo root
(general rules linking the per-language standards), borrowing the
defect-preventing rules from JSF AV C++ / MISRA C++:2023 / AUTOSAR
C++14 / CERT and dropping checker-driven superstition (single-exit,
mandatory `default`, essential-type cast noise) that KLEE/fuzz/UBSan
already cover. C++23 baseline tracking C++26.
Practical consequences:

- Firmware must stay **clang-compilable to LLVM bitcode** (KLEE's input)
  even if the target toolchain is GCC — keep target-specific code
  behind thin shims so protocol and state-machine logic builds for the
  host analyzer. (The freestanding subset also keeps the bitcode clean:
  no libstdc++ exception machinery for KLEE to choke on.)
- **Toolchain consequence (feeds §5):** freestanding C++ needs a real
  C++ compiler — GCC/clang. SDCC is C-only, so this decision all but
  rules out 8051-class parts (EFM8/STC) and favors RISC-V/ARM
  (CH32V003, RP2040-class).
- Protocol logic is factored host-testable (parsers, state machines,
  fault-handling decisions) so KLEE harnesses and property tests can
  reach it without the MCU.
- KLEE harnesses target the protocol invariants first: frame
  encode/decode round-trips, ring state-machine progress, behavior
  under injected garbage (the babbling-idiot case, §3).

Test philosophy: **SQLite's doctrine, plus symbolic verification on
top.** The SQLite project is the reference for what
"rigorously tested" means for a small, everywhere-deployed C codebase;
the parts that transfer to oparroy firmware and the DSL:

- **Coverage measured on the release build, not a test build** —
  SQLite enforces 100% branch (MC/DC-style) coverage of the *deployed*
  configuration, so tests exercise what actually ships. For oparroy:
  coverage of the freestanding build, and on-target coverage
  measurements from HIL runs where feasible.
- **Fault injection at every boundary** — SQLite simulates OOM and I/O
  errors at every call site that can fail. oparroy's equivalents:
  bus/line errors, timer glitches, dropped/partial frames, watchdog
  timeouts, brown-outs — injected through the host shims so every
  failure path is reachable in test.
- **Structure-aware fuzzing as a first-class harness** — SQLite runs
  dbsqlfuzz continuously. oparroy: libFuzzer/AFL++ harnesses on the
  frame parser and ring state machine (alongside, not instead of, the
  KLEE harnesses — fuzzing finds what the prover's assumptions miss,
  the prover proves what fuzzing can't reach).
- **Multiple independent test harnesses** — SQLite keeps four; a bug
  found by one that another missed gets analyzed for why. oparroy:
  unit tests, KLEE, fuzzing, ngspice subcircuit sims, HIL — diversity
  is deliberate.
- Symbolic verification (KLEE) is the layer SQLite *doesn't* have; it
  complements the above by exhausting small state spaces (frame
  grammar, ring state machine) rather than sampling them.

Firmware build system: **Meson + ninja**. The build matrix is wide
even though the file count is small: three toolchains (riscv
GCC node, arm GCC supervisor, clang host) × build flavours (host
objects, LLVM bitcode for KLEE, fuzzers, coverage-instrumented release)
plus custom outputs (KLEE runs, DSL-generated headers per §7). Meson
covers that natively — one cross/native file per toolchain, per-target
flag overrides, `custom_target()` for bitcode/KLEE, and the built-in
test runner driving coverage-on-release (clang source-based
instrumentation + llvm-cov branch reporting, chosen over
`b_coverage`/gcov — gcov-format data degrades on C++ at -O2, and
llvm-cov reports exact branch coverage with tools already in the
flake's LLVM set). CMake was the
runner-up (toolchain-file ceremony, verbose custom commands); GNU make
loses on the multi-toolchain matrix; tup ruled out (FUSE dependency,
thin ecosystem). Provisioned through the flake like everything else.
The project's default `buildtype` is pinned to `plain`: the nix
cc-wrapper appends `-D_FORTIFY_SOURCE` *after* all user
flags whenever it sees an explicit `-O` (meson debug's `-O0` included),
and glibc `#error`s on that under `-Werror` at `-O0` — freestanding has
no libc for fortify to call into anyway. Optimized flavours are chosen
per build dir at setup time.

Build reproducibility: **bit-for-bit reproducible builds are a hard
constraint** — same source tree + same `flake.lock` ⇒ byte-identical
artifacts, on any machine. The flake's pinned toolchains
are the foundation; on top of it: no `__DATE__`/`__TIME__`/
`__TIMESTAMP__` ([code-std-cpp.md#1-language-and-toolchain](code-std-cpp.md#1-language-and-toolchain) — version identity comes from git,
matching §7's board-version rule), `-ffile-prefix-map`/
`-fdebug-prefix-map` on every compile so no build paths leak into
outputs, deterministic archive mode, content-derived linker build-id.
A check target builds twice and compares hashes — a reproducibility
failure is red like a failing test.

Tool provisioning: **nix flake + uv, each in its lane**. Exotic tools
will accumulate (provers, cross-compilers, ngspice, KiCad, SDCC), so:

- The **flake dev shell** provides every non-Python tool, pinned by
  `flake.lock` — including `uv` itself. Same flake drives CI, so local
  and CI toolchains are identical by construction.
- **uv** owns the Python side alone: `pyproject.toml`/`uv.lock`, the
  project venv, and its own standalone CPython builds (static, run fine
  under nix — no nixpkgs Python in the loop). Rule: Python packages
  come *only* from uv; everything else comes *only* from nix.

## 9. Open design questions

Decided-to-be-decided problems that aren't yet work cards (the card that
resolves each is in KANBAN.md):

- **Intermittent connector faults** (§3) — protocol re-route vs hardware
  auto-bypass vs both; the dual-ring substrate is settled (§3), the
  direction-flap policy is not.
- **Debug transport** (§6) — per-node UART vs shared bus, connector
  style.
- **Node-board stackup and thickness** (§6) — **resolved: 2-layer,
  0.8 mm.** The §1 cost driver won: the board is tiny, single-sided,
  and its back is two connectors plus pass-through, so 4-layer's
  routing room buys nothing. 0.8 mm over 1.0 mm for feel,
  accepting more flex under the IDC mating shear the hand-soldered SMD
  headers take (§3). JLCPCB's exact 2-layer thickness offerings verify
  at quote time.
- **Payload terminal on the standalone node board** (§5, §6) —
  tracked as kristofferkoch/oparroy#35, "Add potentiometer to
  single-node design?". The node board as settled wires no payload
  pads at all: pot/buzzer/buttons/debug TX stay NC and only PC7 gets a
  test pad, because human-facing I/O was designed onto the CI board's
  tiles (§6 dual role) — the production-form node is a pure comms
  bead. The open question is whether the single-node board grows a
  payload terminal, and in what form. The hooks already exist: the
  pin map reserves the §5/§6 payload superset (pot on PD6/ADC, buzzer
  PWM on PC4/TIM1_CH4, buttons on FT PC5/PC6, spares PC1/PC7),
  actuator-class power is the UNREG rail's job (§2.1: per-payload
  regulation, never per-node), and any external terminal follows the
  §7 terminal rule (series R, FT pins, per-terminal TVS). User
  leaning: a row of unpopulated PTH holes, so a function can be
  hand-soldered to specialize individual nodes — issue #35's DNP 3-pin
  pot footprint is the minimal instance.
- **Cable reach** (§2) — maximum segment length unamplified, and with
  an amplifier/re-driver node in the segment; line coding is settled
  (§2), so this is drive strength, comparator sensitivity, and cable
  characteristics.
  Answered by simulation first, then measured on the test board.
- **Coverage threshold gate** (§8) — the coverage instrumentation
  measures branch coverage of the release build (llvm-cov,
  informational only: 82% of 122 branches at landing). Whether to gate
  the build on a threshold,
  and at what red line, is undecided; the infrastructure supports it
  (`llvm-cov export` JSON) once the suite matures. Also open: whether
  the shipped node image builds at the measured `-O2` or at `-Os`
  (16 KB flash). No card yet.

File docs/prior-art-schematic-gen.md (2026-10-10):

# Prior art: automatic schematic generation

Question: what should oparroy's design-review views look like beyond
the dot dump (DESIGN.md §7), and what do we build vs borrow. Sources
linked inline.

## 1. The requirement

DESIGN.md §7 sets the target: "abstraction-level block views in the
Verilog-debugger sense" for human review. The dot dump
(`src/oparroy/dsl/dot.py`) is the minimal rung: a flat bipartite graph —
record node per part, ellipse per net — that Graphviz renders. It
flattens hierarchy, shows no signal flow, no port direction, no symbol
graphics. Fine for eyeballing a ten-part subcircuit; useless for
reviewing a board.

Two view levels fall out of the DSL's own structure:

- **Block view** — subcircuit instances as boxes, ports / port arrays /
  bundles as their interface pins, ring wiring as thick lines. Answers
  the review question "is the board composed right."
- **Detail view** — one subcircuit's parts and nets, signal flow
  left-to-right, power nets as stubs. Answers "is this subcircuit wired
  right."

The DSL knows things a generic layout tool doesn't: `Part.path`
hierarchy metadata, KiCad `PinType` (input/output/power) per symbol pin,
the `power:`-symbol convention marking driven nets, typed parts. View
generation sits on that knowledge — that is the build half of §4.

## 2. Tool survey

### yosys `show`

[`show`](https://yosyshq.readthedocs.io/projects/yosys/en/0.35/cmd/show.html)
emits a Graphviz dot graph of the selected design; dot lays it out.
Fine for a handful of RTL cells; beyond that the layout has no schematic
conventions (no port sides, no symbol shapes, gates as labeled boxes)
and collapses into spaghetti — it is a debugging aid you steer with
`select` filters, not a review document. Same league as our dot dump.

### netlistsvg

[netlistsvg](https://github.com/nturley/netlistsvg) draws SVG schematics
from yosys JSON netlists. Architecture: cell→symbol **skin files** (SVG
templates with named port anchor points), layout by
[elkjs](https://github.com/kieler/elkjs) — the JavaScript port of
Eclipse ELK — running a Sugiyama-family layered layout with **port
constraints and orthogonal edge routing**. Ships a digital skin and an
analog skin (resistors, BJTs, vcc/gnd symbols). Input is flat JSON; no
hierarchy.

Status: v1.0.2 released 2020-12-12, npm registry untouched since
2022-05 — effectively unmaintained, though packaged in nixpkgs. It
remains what yosys-adjacent tooling reaches for (TerosHDL's schematic
viewer pipes yosys → netlistsvg).

Takeaways: ELK-layered plus skins produces recognizably
schematic-looking output; the skin indirection — symbol templates with
port anchors — is the right shape for symbol graphics. The
unmaintained-JS-dependency is the cost.

### d3-hwschematic

[d3-hwschematic](https://github.com/Nic30/d3-hwschematic): d3.js + ELK,
browser viewer, **hierarchy as expand/collapse boxes** — submodules are
nested containers with port anchors on their boundary, which is exactly
the block-view interaction model. ELK does nested/hierarchical layout
natively. Takeaway: hierarchy-in-layout is solved in ELK; the
expand/collapse viewer is a d3 concern a static review SVG doesn't
need.

### SKiDL `generate_schematic`

The most informative datapoint, because it attacks the same problem at a
harder setting: emitting **editable** `.kicad_sch`. devbisme's build log
[SKiDL Has Schematics! (2023-07-14)](https://devbisme.github.io/skidl/generating-editable-schematics-2023-07-14.html)
is the honest account: about 18 months (2021-11 → 2023-07) of a skilled
author's effort from contributed prototype to release 1.2.0. What it
took:

- **Placement**: force-directed (net attraction vs overlap repulsion on
  an alpha schedule), parts grouped into connected/floating blocks,
  Kernighan-Lin orientation optimization, a retry loop inflating part
  bounding boxes 1.25× per attempt until routing succeeds.
- **Routing**: PCB-style — coarse routing cells derived from part
  bounding-box edges, global routing with per-edge capacity, terminal
  assignment, greedy switchbox detailed routing, then "beautifier"
  passes (stub→straight, dogleg→L, cycle removal).
- **Verdict after all that**: "the quality of the schematics still
  needs improvement." And the structural observation that drove most of
  2023's rework: **"you can't route your way out of a bad placement."**

Takeaways: bespoke placement+routing is a research project with a
mediocre ceiling — do not build one. Also note what SKiDL targeted:
*editable* schematics in eeschema, much harder than a static review
SVG, because the output must survive human round-trip editing.

### KiCad netlist import

There is no netlist→schematic path in KiCad at all: eeschema imports no
netlists. pcbnew's netlist import drops new footprints in a pile at the
origin for the human to place
([KiCad forums](https://forum.kicad.info/t/reloading-footprints-in-pcbnew/1089));
the old "place footprints automatically" was an unstack helper, not
placement. So DESIGN.md §7's KiCad-stays-layout-only division also
means **nothing borrowable from KiCad itself** for schematic drawing.

### Commercial ESL / reverse-engineering tools

The commercial niche that does netlist→schematic is reverse engineering:
[ScanCAD's Schematic Generation Module](https://scancad.net/schematic-generation-module/)
ingests OrCAD/PADS/DxDesigner/EDIF/IPC-D-356 netlists and emits
"intelligent" schematics — sold as a viewer/debugger with human cleanup
expected, not as review-grade drawings. Mainstream ESL design entry
(Mentor/Cadence/Altium) draws nothing automatically at schematic level;
decades of attempts have produced no tool whose output experienced
engineers accept without rework. The market verdict matches SKiDL's:
full schematic auto-drawing at human aesthetic standards is unsolved.

## 3. The graph-drawing literature underneath

- **Layered (Sugiyama) framework** — the standard for directed
  node-link diagrams with flow: cycle removal → layer assignment →
  crossing minimization → coordinate assignment → edge routing. The
  [PGF/TikZ graph-drawing manual's layered-layout
  chapter](https://tikz.dev/gd-layered) is a good compact spec.
  Crossing minimization is NP-hard; practice is barycenter/median
  sweeps. Brandes–Köpf (2001) is the standard fast coordinate
  assignment. Graphviz `dot` (Gansner–Koutsofios–North–Vo 1993), ELK
  Layered, and grandalf all implement this family.
- **Orthogonal drawing** — bend minimization as a flow problem
  (Tamassia 1987) inside the topology–shape–metrics pipeline: the
  classic way to get the 90° wiring schematics want.
- **Ports and hyperedges** — what separates a *schematic* layout engine
  from a graph drawer: pins live at fixed points on symbol outlines
  (port constraints), and a net is a hyperedge touching N pins, not a
  set of pairwise edges. [ELK
  Layered](https://eclipse.dev/elk/reference/algorithms/org-eclipse-elk-layered.html)
  handles both natively (port sides, orthogonal and hyperedge routing) —
  the concrete capability netlistsvg and d3-hwschematic borrow. ELK's
  architecture paper: [arXiv:2311.00533](https://arxiv.org/html/2311.00533v1).
- **What the literature does not solve: schematic semantics.** No
  layout engine knows that GND points down, that series passives chain
  on a horizontal signal path, that a current mirror wants symmetry,
  that a decoupling cap is a stub off a rail. That gap is the
  difference between a valid drawing and a readable schematic, and it is
  why auto-drawn analog schematics read as wrong even when the topology
  is right. At *block* level the gap barely matters — boxes and thick
  wires are the abstraction. At *detail* level we get partway with
  pin-type direction hints and power-stub collapsing, and accept the
  rest.

## 4. Build vs borrow — recommendation

**Borrow the layout engine. Build the view extraction. Never build a
placement/routing engine.**

Layout-engine candidates, ranked for oparroy:

1. **grandalf** ([GitHub](https://github.com/bdcht/grandalf),
   [PyPI](https://pypi.org/project/grandalf/)) — pure-Python Sugiyama
   layered layout, uv-installable, no runtime beyond Python,
   deliberately hackable ("simple enough to tweak and hack any
   part"). Two caveats verified against the 0.8 source:
   **no orthogonal router** — the shipped edge routers are
   straight-line, spline, and rounded-corner, so the 90° wiring is the
   piece we'd patch in — and the license is **GPLv2 | EPLv1**: take
   EPL-1.0 and depend on it unmodified via uv, because distributing a
   patched copy drags our patches under EPL (patching stays feasible,
   but as an upstreamed or separately-published change, never vendored
   into this MIT tree). Latest release 0.8 (2023-01) — quiet, like
   netlistsvg; pure Python over tiny graphs makes that low-risk.
   Slower and less featured than ELK, but our graphs are tiny: a board
   is tens of subcircuit boxes, a subcircuit is tens of parts. Fits
   the own-the-IR philosophy (§7): a pure-Python Sugiyama takes
   schematic-specific rules (port sides, power stubs) where patching
   ELK does not.
1. **ELK via elkjs** — the capability leader (ports, hyperedges,
   hierarchy, orthogonal routing — everything netlistsvg uses), but
   drags Node.js into a Python pipeline; provisionable via the flake,
   still friction, and netlistsvg itself is unmaintained. The fallback
   if grandalf's output quality disappoints, and the only candidate
   with orthogonal routing built in.
1. **Graphviz dot** — already the baseline. No real port support, weak
   hyperedges; `splines=ortho` exists but fights record nodes. Keep for
   the flat dump; don't extend it.

Build (oparroy-owned, deliberately thin):

- **View extraction over the IR** — the semantics no engine has:
  - Block view: one box per subcircuit instance (`Part.path` already
    carries the metadata), ports / port arrays / bundles as box pins;
    bundles render as single thick wires.
  - Detail view: direction hints from KiCad `PinType` (inputs left,
    outputs right) to seed layering; `power:`-symbol nets collapse to
    named stubs (SKiDL's floating-group trick); series passives
    optionally collapse into labeled wire segments.
  - Port direction tags (T7bd's planned `Input`/`Output`/`InOut` on
    ports, KANBAN.md) are the block view's natural input — the view
    work lands after or with T7bd.
- **Symbol graphics**: reuse KiCad symbol geometry. `kicadlib.py`
  parses pins today, not graphics — extending it to read symbol drawing
  primitives yields netlistsvg-style skins for free, from the same
  libraries the netlist emitter validates against. Prior art exists:
  SKiDL's `generate_svg()` already converts KiCad library symbols into
  netlistsvg skins — the conversion is proven; ours would live
  in-tree. Until then, generic boxes with pin names suffice for
  review.
- **Output**: static SVG, golden-tested like the netlist emitter's
  byte-identical goldens. Not `.kicad_sch` — editable output is
  SKiDL's trap and buys review nothing.

Explicitly **not** built: a placement engine, a router, an interactive
viewer (d3-hwschematic shows the shape if one is ever wanted).

Sequencing: **block view first** — small graphs, highest review value,
exercises extraction before layout quality matters. Then the detail
view on grandalf, golden-SVG tests in the house style.

Follow-up: **DSL review views: block +
detail**, blocked by DSL connection sugar.

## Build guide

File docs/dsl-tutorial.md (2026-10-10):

# DSL tutorial

A guided tour of the design-capture DSL (`src/oparroy/dsl/`, the
project's single source of truth for schematics). This doc teaches by
doing; [dsl-reference.md](dsl-reference.md) is the API map, and
[DESIGN.md §7](../DESIGN.md#7-design-capture-dsl) records *why* the DSL
is shaped this way. Read this one first.

The pipeline, in the order a design flows through it:

1. **Capture** — plain Python builds the IR: parts, nets, subcircuit
   instances.
1. **Transforms** (CI board only) — instrumentation applied as data
   over the hierarchical capture.
1. **Footprint assignment** — per-instance overrides over the class
   defaults.
1. **Check** — one validation pass, findings batched as `Issue`s.
1. **Annotation** — capture paths mapped to refdes, and back from
   pcbnew.
1. **Emit** — KiCad netlist, ngspice DUT netlist, dot graph, firmware
   pin header.

Every code block below is quoted verbatim from
[tests/test_dsl_tutorial.py](../tests/test_dsl_tutorial.py), which
pytest exercises — the tutorial cannot drift from the API. Run it:

```
uv run pytest tests/test_dsl_tutorial.py
```

## Setup

The nix dev shell provisions everything non-Python (KiCad libraries,
ngspice, uv itself); uv owns the Python side. Real captures resolve
symbols and footprints from the KiCad libraries via
`KiCadLibraries.from_env()`, which reads env vars the dev shell exports
— outside the shell it raises `LibraryError`. Tests don't need KiCad:
`tests/conftest.py` carries stub symbol and footprint tables
(`StubSymbols`, `StubFootprints`), and the worked example uses them, so
it runs anywhere pytest does.

## Your first circuit

The example: a two-channel RC low-pass filter board. One `RcFilter`
subcircuit, instantiated twice.

A circuit is parts and nets with explicit names — you pick every
reference designator and net name at capture time, because those names
are the stable identity everything downstream (checks, annotation,
tstamps) keys on. Parts come from *typed* classes: construction carries
the wiring, so a misspelled pin name fails at the call site, not in a
later netlist audit. Footprints default per *bin* — a subclass per
footprint family:

```python
class R0603(Resistor):
    """Resistors from the 0603 bin: the footprint is the class default.

    The real bins resolve from the parts DB (``design/parts_db.py``);
    these stub footprints stand in so the example runs without the
    KiCad libraries.
    """

    default_footprint = "StubFP:R_0603"

class C0603(Capacitor):
    """Capacitors from the 0603 bin."""

    default_footprint = "StubFP:C_0603"
```

(In a real capture you don't declare bins by hand —
`design/parts_db.py` binds them from the parts DB, which also carries
assembler-stock status.)

The subcircuit. Ports are the interface: nets the outside world
reaches. They can carry *limit ranges* — `source` is what the port
drives out, `sink` what it accepts — and the checker verifies that a
connected sink's range covers the source's:

```python
class RcFilter(Subcircuit):
    """One RC low-pass channel: ``in`` → Rs → ``out``, Cs to GND.

    The ports carry limit ranges as interface contracts: ``in``
    accepts 0..3.3 V from the signal source, ``out`` drives 0..3.3 V
    toward the ADC. An instantiating parent's declared ranges are
    checked for containment against these.
    """

    def capture(self, circuit: Circuit) -> None:
        """Build the channel: ports in/out/GND, parts Rs/Cs."""
        in_ = circuit.port("in", sink=Limits(voltage=Interval(0, 3.3)))
        out = circuit.port("out", source=Limits(voltage=Interval(0, 3.3)))
        gnd = circuit.port("GND")
        circuit.part("Rs", R0603("4k7", a=in_, b=out))
        circuit.part("Cs", C0603("100n", a=out, b=gnd))
```

Three things to internalize here:

- **Construction *is* wiring.** `circuit.part("Rs", R0603("4k7", a=in_, b=out))` places the resistor and connects its pins in one call.
  Pin keywords are keyword-only; only unpolarized two-pin parts
  (`Resistor`, `Capacitor`) take the value positionally — anything
  where orientation matters (`Diode`, `Led`, `Bat54s`) is keyword-only
  throughout. `connect()` exists for symbol-placed parts
  (`circuit.part("R1", symbol="Device:R")`) and multi-unit packages.
- **Ports wire like nets inside the subcircuit.** The difference shows
  up at instantiation and in the checker: ports are exempt from the
  dangling-net checks, because reaching outside is their job.
- **`Interval`s are closed, containment inclusive** — `Interval(0, 3.6)`
  covers `Interval(0, 3.3)`. An undeclared side is *no data*, not an
  error.

The board instantiates the filter twice and binds every port by
keyword:

```python
def capture(symbols: SymbolTable) -> Circuit:
    """Build the tutorial board: two filter channels sharing one GND."""
    board = Circuit("filter-board", symbols)
    ain1 = board.port("ain1", source=Limits(voltage=Interval(0, 3.3)))
    ain2 = board.port("ain2", source=Limits(voltage=Interval(0, 3.3)))
    adc1 = board.port("adc1", sink=Limits(voltage=Interval(0, 3.6)))
    adc2 = board.port("adc2", sink=Limits(voltage=Interval(0, 3.6)))
    gnd = board.port("GND")
    # "in" is a Python keyword, so that port binds via **-unpacking.
    board.instance("FILT1", RcFilter(), out=adc1, GND=gnd, **{"in": ain1})
    board.instance("FILT2", RcFilter(), out=adc2, GND=gnd, **{"in": ain2})
    return board
```

`instance()` runs the subcircuit's capture into a child circuit and
checks the binding immediately: every declared port must be bound, and
no binding may name a port that doesn't exist — interface drift breaks
the capture that introduced it, not a later stage. (The `**{"in": ...}`
dance is how you bind a port whose name is a Python keyword.) Note the
directions: the board's `ain1` declares `source` (the outside world
drives it), each filter's `in` declares `sink` — containment checks
that pairing.

## Checking

`check()` is the one validation pass. Structural invariants — duplicate
refs, a pin on two nets, `/` in a name — raise `DefinitionError` at
capture; everything semantic batches into a list of `Issue`s with a
`Severity` (`warning`, `error`, `waived`). `raise_on_errors` turns the
batch into a `CheckError` for scripts:

```python
def test_board_checks_clean(symbols: StubSymbols, footprints: StubFootprints) -> None:
    assert check(capture(symbols), footprints=footprints) == []
```

What the checker reports: parts without value or footprint, footprints
missing from the libraries or mismatching the symbol's filters,
unconnected pins, empty and single-pin nets, multiple power outputs on
one net, power inputs with no driver — and the port-range containment
contract. Declaring the ADC sink narrower than the filter's output
range makes it fire, addressed by hierarchical path:

```python
def test_range_containment_fires(symbols: StubSymbols) -> None:
    board = Circuit("narrow-adc", symbols)
    ain = board.port("ain", source=Limits(voltage=Interval(0, 3.3)))
    adc = board.port("adc", sink=Limits(voltage=Interval(0, 1.8)))
    gnd = board.port("GND")
    board.instance("FILT1", RcFilter(), out=adc, GND=gnd, **{"in": ain})
    errors = [i for i in check(board) if i.severity is Severity.ERROR]
    assert len(errors) == 1
    assert errors[0].check == "range-containment"
    assert errors[0].path == "FILT1/out"
```

When the finding is deliberate, you don't suppress it with a comment —
you *waive* it, as data in the capture, addressed by check id and path,
with a reason. The error degrades to a `WAIVED` finding: visible in
every report, auditable in review, and a waiver that stops matching
anything warns as stale:

```python
def test_waiver_degrades_the_error(symbols: StubSymbols) -> None:
    board = Circuit("narrow-adc", symbols)
    ain = board.port("ain", source=Limits(voltage=Interval(0, 3.3)))
    adc = board.port("adc", sink=Limits(voltage=Interval(0, 1.8)))
    gnd = board.port("GND")
    board.instance("FILT1", RcFilter(), out=adc, GND=gnd, **{"in": ain})
    board.waive(
        "range-containment",
        "FILT1/out",
        reason="the ADC pin is 1V8-only by design; the divider guarantees the level",
    )
    issues = check(board)
    assert [issue.severity for issue in issues] == [Severity.WAIVED]
    raise_on_errors(issues)
```

## Flattening: what checks and emitters see

Hierarchy is capture-time structure. `flatten()` reduces it to the flat
IR every downstream stage consumes: instance names prefix part
references and internal nets (`FILT1/Rs`), and each port net merges
into the net the instance bound it to:

```python
def test_flatten_prefixes_instance_names(symbols: StubSymbols) -> None:
    flat = capture(symbols).flatten()
    assert sorted(flat.parts) == ["FILT1/Cs", "FILT1/Rs", "FILT2/Cs", "FILT2/Rs"]
    # Each port net merges into the net its instance bound it to; the
    # internal names are gone.
    assert "FILT1/in" not in flat.nets
    assert {pin.part.ref for pin in flat.nets["ain1"].pins} == {"FILT1/Rs"}
    assert {pin.part.ref for pin in flat.nets["GND"].pins} == {
        "FILT1/Cs",
        "FILT2/Cs",
    }
```

You almost never call `flatten()` yourself — `check`, the emitters, and
the annotation stage all flatten implicitly and report hierarchical
paths. The explicit names at every level are what keep those paths
stable across source edits. (The one stage that must see the hierarchy
is `apply_transforms` — it runs *between* capture and check; see
[dsl-reference.md](dsl-reference.md).)

## Annotating and emitting

Capture paths (`FILT1/Rs`) are the stable identity; the board carries
refdes (`R1`). Annotation is an explicit, repeatable stage: `annotate`
maps paths to refdes (preserving a `prior=` table for parts that
survive an edit), `apply_annotation` renames the IR for emission, and
`annotation_from_pcb` folds pcbnew's geographic renumbering back. The
tables are JSON on disk, byte-identical on write — a renumbering diff
in review is exactly the placement change. Emitters consume the
annotated IR:

```python
def test_netlist_emission(symbols: StubSymbols) -> None:
    board = capture(symbols)
    # Pre-annotation, comp refs are the hierarchical capture paths.
    assert '(comp (ref "FILT1/Rs")' in emit_netlist(board)
    # Annotation maps capture paths to refdes; emission for the board
    # runs on the annotated IR.
    netlist = emit_netlist(apply_annotation(board, annotate(board)))
    for ref in ("R1", "R2", "C1", "C2"):
        assert f'(comp (ref "{ref}")' in netlist
    assert '(comp (ref "FILT1' not in netlist
    assert '(name "GND")' in netlist
```

All emitters are byte-identical across runs — natural-sorted iteration,
content-derived timestamps, no dates or paths leak into the output — so
golden files pin them in CI.

The emitter family:

- **`emit_netlist(circuit)`** — the KiCad `.net` pcbnew imports. Power
  symbols (`power:+3V3`-class) are schematic-only net markers and stay
  out of the components and net nodes, matching eeschema.
- **`to_dot(circuit)`** — the bipartite parts/nets Graphviz view for
  human review.
- **`emit_spice(circuit, name=..., models={...})`** — the ngspice DUT
  `.subckt`; stimulus and `.meas` assertions live in external bench
  decks (`circuits/**/tb_*.cir`). Only symbols with a declared binding
  emit, and the caller passes the `.model` bodies — a part's value
  names its model. `python -m design.watchdog_chargepump --spice` is a
  working example.
- **`emit_pin_header(pin_map, ...)`** — the freestanding-C++ header the
  firmware includes, from the pin map (`design/node_pins.py`;
  regenerate with `python -m design.node_pins > firmware/node/pins.hpp`). `check_pin_map` is the GPIO-budget check
  over the same table: requests are by *function*, pads bind late as
  refinement data.

The real captures double as runnable end-to-end examples — in the dev
shell:

```
python -m design.node --dot            # node board, Graphviz view
python -m design.node                  # check + KiCad netlist
python -m design.watchdog_chargepump   # the §4 watchdog, standalone
```

## When things go wrong

Two failure channels, by design:

- **Capture-time: `DefinitionError`** (and `TypeError` from a typed
  part's signature). Duplicate refs or net names, a pin already on
  another net, `/` in any name (it's the hierarchy separator), unknown
  or unbound ports at `instance()`, footprint overrides naming unknown
  parts. These raise immediately, from the offending line.
- **Check-time: batched `Issue`s.** Everything electrical or
  board-facing, so one run reports all of it.

The common beginner errors, and what they mean:

| Symptom | Cause |
| --- | --- |
| `DefinitionError: duplicate part reference 'R1'` | Refs are explicit; pick another name |
| `DefinitionError: ... must not contain '/'` | `/` is the hierarchy path separator |
| `TypeError` from a typed part | Misspelled or missing pin keyword — construction is wiring |
| `DefinitionError: no net named 'vcc'` | Declare nets (`net`/`port`) before wiring them |
| `DefinitionError: instance 'FILT1': ports ['out'] left unconnected` | `instance()` binds *every* port |
| `DefinitionError: instance 'FILT1': the subcircuit has no ports ['inp']` | Interface drift — the subcircuit renamed the port |
| `error: R3 has no footprint (pcbnew needs one)` | No class default and no override; assign one |
| `warning: net 'x' has a single pin` | Dangling internal net; ports are exempt by design |
| `error: port 'FILT1/out' ... sink range must cover source` | Range containment; fix the design or `waive` with a reason |
| `warning: waiver ... matched no issue` | Stale waiver — the finding it excused is gone; delete it |

## Where next

- [dsl-reference.md](dsl-reference.md) — the full API map: port arrays
  and bundles, component sockets and multipacking, the parts DB,
  instrumentation transforms and the equivalence proof, the
  layout-checking side.
- [DESIGN.md §7](../DESIGN.md#7-design-capture-dsl) — the settled
  design decisions behind the shape you just used.
- `design/node.py` — the node board capture, the largest real user of
  everything above.

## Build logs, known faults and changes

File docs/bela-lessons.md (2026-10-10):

# Bela platform — lessons for oparroy

Prompted by Bernt's tip ("done a lot of right things"). Sources linked
inline. Bela is a real-time audio/sensor platform spun out of Queen
Mary University of London after a
[2016 Kickstarter](http://andrewmcpherson.org/project/bela); now
Augmented Instruments Ltd.

## 1. Real-time I/O architecture: PRU as the I/O engine

Strict **split of responsibilities** on the BeagleBone's AM3358:

- **Linux (Xenomai Cobalt real-time thread)** runs the user's
  `render()` callback — DSP and control logic — with hard scheduling
  guarantees.
- **The PRU (200 MHz deterministic RISC core)** runs hand-written
  assembly (`pru_rtaudio.p` in the [Bela core repo](https://github.com/BelaPlatform/Bela))
  moving every sample between hardware and shared memory. Notably the
  PRU does **not** stream audio — the McASP peripheral does; the PRU is
  "a sort of sophisticated DMA controller" that also bit-bangs SPI to
  the analog ADC/DAC and samples GPIOs, **aligned sample-by-sample with
  the audio clock** ([forum: PRU vs McASP](https://forum.bela.io/d/20-pru-vs-mcasp)).

What it buys ([ICLI 2016 paper](https://web.archive.org/web/20230924141757/http://users.sussex.ac.uk/~thm21/ICLI_proceedings/2016/Practical/Workshops/129_Bela.pdf) — original sussex.ac.uk link 404s, archived copy),
[Hackaday 2016](https://hackaday.com/2016/04/13/bela-real-time-beaglebone-audioanalog-cape/)):

- **Sensors at audio rate**: 8× 16-bit analog at 22.05–88.2 kHz, 16
  digital at 44.1 kHz — sensor reads synchronous with audio, so
  control-to-sound jitter is zero by construction, latency < 1 ms.
- A tiny, auditable blob of assembly owns *all* timing; Linux can be
  rebooted or crash without redesigning the real-time layer.

**Lesson:** validates the PIO argument in
[mcu-research](mcu-research.md) §RP2040: *a small
deterministic engine owns the wire; a bigger non-deterministic host
owns policy*. Two specifics: (a) let a **dedicated peripheral do bulk
streaming** (McASP there; PIO+DMA here), use the programmable engine
only where programmability is needed (per-bit re-timing); (b) keep the
engine's code **small and frozen** — Bela's PRU blob barely changed
across a decade of Linux images. Bela Gem on PocketBeagle 2 (AM6254,
333 MHz PRUSS) reuses the same architecture
([BeagleBoard blog, 2025-07-10](https://www.beagleboard.org/blog/2025-07-10-bela-gem-brings-ultra-low-latency-audio-to-pocketbeagle-2)).

## 2. Sensor/IO ecosystem: Trill

[Trill](https://learn.bela.io/products/trill/about-trill/) is Bela's
capacitive-touch family (Bar, Square, Craft, Hex, Ring, Flex),
Kickstarter 2019. What they standardized:

- **One electrical interface**: 4-wire I2C + power, physically
  **JST-SH QWIIC connectors** ([Gliss update](https://www.crowdsupply.com/augmented-instruments/gliss/updates/the-next-generation-of-trill-sensors)),
  plus a Trill Hub breakout with on-board pull-ups for chaining.
- **One firmware, many shapes**: shared register protocol
  ([Trill datasheet](https://www.mouser.com/catalog/specsheets/Bela_TRILL_sensors_datasheet.pdf));
  host library auto-detects sensor type. Libraries for Bela (LGPL),
  Arduino (BSD-3), Linux ([GitHub: BelaPlatform/Trill](https://github.com/BelaPlatform/Trill)).
- **Deliberate address plan**: distinct default address per type
  (Bar 0x20 … Flex 0x48) plus 8 alternates via **tri-state solder
  bridges** (2×3 pads = 9 values), with docs covering even the
  "bridging both sides shorts VCC to GND" failure mode
  ([All about I2C](https://learn.bela.io/using-trill/all-about-i2c/)).
- **Smart-node partitioning**: touch processing (position + size,
  sensitivity tuning) happens **on the sensor's own MCU**; the host
  gets cooked data. Original Trill: Cypress PSoC 1; next-gen Gliss:
  STM32G491 ([gliss-firmware](https://github.com/BelaPlatform/gliss-firmware)).

**Lesson:** precedent for *oparroy nodes as smart peripherals with a
standardized cooked-data interface*, and for solving multi-instance
addressing **in hardware instead of a provisioning step**. Their
docs-driven treatment of I2C pull-up/address-collision pitfalls is
worth imitating for oparroy's accelerometer/captouch guide.

## 3. Developer experience

Adoption engine, in evidenced order of importance:

1. **Zero-install IDE in the browser**: board appears as `bela.local`;
   the IDE edits, cross-compiles *on the board*, runs projects;
   in-browser oscilloscope, console, interactive pin diagram
   ([IDE wiki](https://github.com/BelaPlatform/bela/wiki/Bela-IDE)).
1. **Examples as curriculum**: hundreds of categorized examples; docs
   say load one, save a copy, mutate it.
1. **A knowledge base, not a wiki**: [learn.bela.io](https://learn.bela.io)
   is tutorial-shaped; free YouTube C++ course; active
   [forum](https://forum.bela.io).
1. **Meet users in their language**: C/C++, Pure Data, SuperCollider,
   Csound, FAUST, Max RNBO, Arduino-style — same core engine behind
   all.
1. IDE is GPLv3, ships with every board.

**Lesson:** oparroy's DSL is the "single source of truth" advantage;
spend the savings on (a) a **golden live demo** (RP2040 supervisor +
ring visualizer) that works in minutes, and (b) **task-shaped docs**
("add a button node", "debug a dead ring segment"), not API-shaped
ones.

## 4. Open hardware / business model

Per their [licensing page](https://learn.bela.io/products/products-overview/open-source-licenses/)
and [Bela Gem Crowd Supply](https://www.crowdsupply.com/bela/bela-gem-stereo-and-multi):

- **Layered licenses**: hardware CC-BY-SA, core software **LGPL 3.0**
  (commercial products can link dynamically), IDE **GPL 3.0**, host
  libraries permissive (BSD-3).
- **Dual licensing as revenue**: closed use → commercial license,
  priced transparently for Trill (from £500 / 500 pieces).
- **Trademark is the moat**: "Bela" trademarked; community products use
  "X for Bela" naming and a community logo. Protocol/files free; the
  *brand* is not.
- **Crowdfunding every launch**: Kickstarter 2016 (Bela), 2019 (Trill),
  ~2022 (Gliss), Crowd Supply 2025 (Bela Gem). Retail via own shop +
  Mouser. Bela Gem released *unrouted* PCB files under CC BY-NC — a
  partial-closure experiment.
- University spin-out gave credibility and community before revenue.

**Lesson:** copyable core = **permissive protocol + copyleft reference
implementation + trademarked name**, permissive node-side libraries for
adoption. A sub-3-NOK node protocol has nothing to dual-license — the
asset is the standard and the supervisor tooling. (Note: oparroy is
currently settled on plain MIT — revisit only if the standard/tooling
framing above resonates.)

## 5. Testing / manufacturing

Thinnest documented area; one very relevant recent data point — the
[Bela Gem production update (2025-12-22)](https://www.crowdsupply.com/bela/bela-gem-stereo-and-multi/updates/end-of-year-status-report-on-production-software-testing-and-the-new-bela-ide):

- **"Every Bela product is tested in operation before it goes out the
  door."**
- In-house **test jig**: clamped fixture with **spring-loaded pogo
  pins**, run **after SMT but before through-hole soldering** —
  catching failures at the cheapest rework point. The jig caused a
  multi-week slip ("teething problems"), reported publicly; paid off
  with "a very high yield rate."
- Software validated by **beta testers on real hardware** under stress
  workloads.

**Not found:** any public hardware-in-the-loop CI — the Bela core repo
has no GitHub Actions; if CI exists it isn't public. Bernt's claim
likely refers to architecture/UX, not CI.

**Lesson:** jig timing (post-SMT, pre-through-hole) and
test-every-unit-in-operation apply directly to oparroy's test board;
the jig-delay story warns to budget the test rig as a first-class
deliverable — aligning with hands-off-HIL from day one (DESIGN.md §6,
§8).

## Transferable to oparroy — decision map

| Bela decision | oparroy design area |
| --- | --- |
| Tiny frozen PRU assembly blob owns all wire timing; host does policy | **PHY engine**: keep the PIO re-timing RX/TX program minimal, versioned separately from supervisor firmware |
| Dedicated peripheral (McASP) streams bulk; programmable engine only where needed  | **PHY engine**: PIO + DMA chaining; CPU out of the bit path |
| Sensors sampled synchronously in the engine's timebase | **Protocol**: timestamp/slot node telemetry in the ring frame, not polled ad hoc |
| Smart sensor nodes; cooked data over a standard 4-wire connector | **Node I/O**: nodes pre-process (debounce, captouch thresholding, accel FIFO), answer with digested values |
| Hardware address selection via tri-state solder bridges, documented failure modes | **Node I/O / protocol**: hardware node-ID strategy instead of provisioning; docs teaching the short-circuit-class mistakes |
| Per-type default addresses + one shared register map, auto-detect in host lib | **Protocol**: fixed node-type IDs in enumeration; supervisor auto-detects type |
| One firmware across a sensor family | **Node firmware**: single MCU image, personality by type ID — one HIL target |
| Zero-install browser IDE, examples-as-curriculum, scope built in | **Tooling**: ship a runnable ring demo + live visualizer (RP2040 golden reference) before breadth of features |
| Layered licensing: permissive libs, copyleft core, trademarked name | **Repo/legal**: permissive node library, copyleft supervisor/tooling, trademark "oparroy" early — only if the settled plain-MIT pick is revisited |
| In-house pogo-pin jig, test post-SMT/pre-through-hole, every unit in operation | **Test board**: jig as its own deliverable; test at the cheapest rework stage |

**Could not verify:** (a) any Bela hardware-in-the-loop CI — appears
not public; (b) whether Bela Gem reuses the original PRU assembly
unchanged; (c) current Trill production firmware (public repo reflects
the PSoC generation).

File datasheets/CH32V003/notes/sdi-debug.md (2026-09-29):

# CH32V003 SDI debug (PD1)

Part of the CH32V003 notes — part identity, source documents, and citation
conventions in [facts.md](facts.md). Sources: DS0 §1.4.18; RM §7.3.2.1,
ch.18; QDM (QingKeV2 debug manual v1.0, vendored 2026-09-29 from
openwch/ch32v003).

- Single-wire debug on **PD1 (SWIO)**, enabled out of reset. HSI must be
  running for SDI (DS0 §1.4.18).
- AFIO_PCFR1 SWCFG\[2:0\]: 0xx = SDI enabled; 100 = SDI off, PD1 becomes
  GPIO — note this is self-locking against the debugger until next reset.
- Pin conflicts: PD1 defaults carry TIM1_CH3N / ADC_ETR2; remaps carry
  I2C_SCL_1 and USART_RX_1. Keep those functions off PD1 while debugging.
- DBGMCU_CR (CSR address 0x7C0): TIM1_STOP/TIM2_STOP/WWDG_STOP/
  IWDG_STOP freeze counters in debug halt; SLEEP/STANDBY bits keep
  clocks up in low-power debug.

Quirks (brick/unbrick, programmer traps): see [quirks.md](quirks.md)
§Debug / SDI & recovery and §Toolchain / programmer pitfalls.

## Wire protocol (QDM ch.2)

Half-duplex on the single SWIO line, idle high, open-drain style: bits
are pulse-width encoded in the low phase. T is the target debug-interface
clock period (T = 125 ns per PicoRVD, which clocks the interface at
HSI/3 = 8 MHz — QDM defines T abstractly, no fixed rate).

- Normal mode 2x (default out of reset): data 1 = low (T,4T) then high
  (T,16T); data 0 = low (6T,64T) then high (T,16T); stop = high ≥ 18T
  (QDM §2.2).
- Fast mode 1x: data 1 = low (T,2T); data 0 = low (4T,32T); stop = high
  ≥ 10T (QDM §2.2). PicoRVD reports normal mode is what actually works;
  stop < 2250 ns fails (PicoRVD `singlewire.pio` comments, unverified by
  us on the bench).
- Reset the interface by holding SWIO low for an extended time (QDM §2.2
  "a certain time"; PicoRVD uses ~8 µs and notes 256T = 32 µs).
- New Packet: start bit 1, 7-bit register address MSB-first, R/W bit
  (1 = host write, 0 = host read), 32-bit data MSB-first, optional even
  parity bit — omit parity by sending the stop character right after the
  last data bit (QDM §2.1). Programmers in the wild skip parity.
- Bypass Packet: start bit 0 + 32-bit data, reusing the previous New
  Packet's address and direction — the fast path for repeated access to
  one register (QDM §2.1).

Interface config registers (7-bit addresses, QDM §2.3): CPBR 0x7C
(read-only capability), CFGR 0x7D, SHDWCFGR 0x7E. Writes need KEY =
0x5AA5 in bits [31:16]; to change config, write SHDWCFGR first, then
CFGR to commit (QDM §2.4 — e.g. 0x5AA50400 to both enables slave
output). Current silicon: IO_FREE mode only, even parity only (no
CRC8), stop-factor 8x only.

## Debug module behind the wire (QDM ch.3)

The transport carries register read/writes to a debug module that
follows RISC-V External Debug Support v0.13.2: dmcontrol 0x10, dmstatus
0x11, hartinfo 0x12, abstractcs 0x16, command 0x17, abstractauto 0x18,
progbuf0-7 0x20-0x27, haltsum0 0x40 (QDM §3.1). Halt/resume/reset via
dmcontrol; GPR/CSR/memory access via abstract commands or the 8-word
program buffer (a short progbuf must end in `ebreak`/`c.ebreak`).
Flash programming runs through this same module (64-byte fast pages,
RM §18 / [flash-option-bytes.md](flash-option-bytes.md)).

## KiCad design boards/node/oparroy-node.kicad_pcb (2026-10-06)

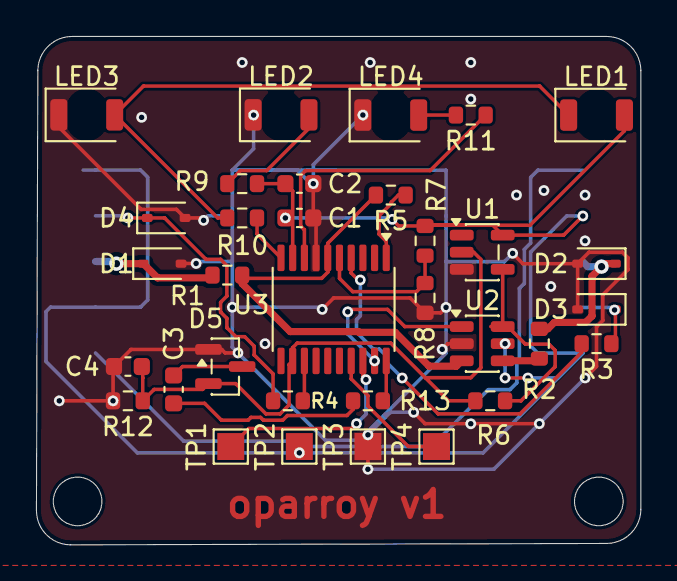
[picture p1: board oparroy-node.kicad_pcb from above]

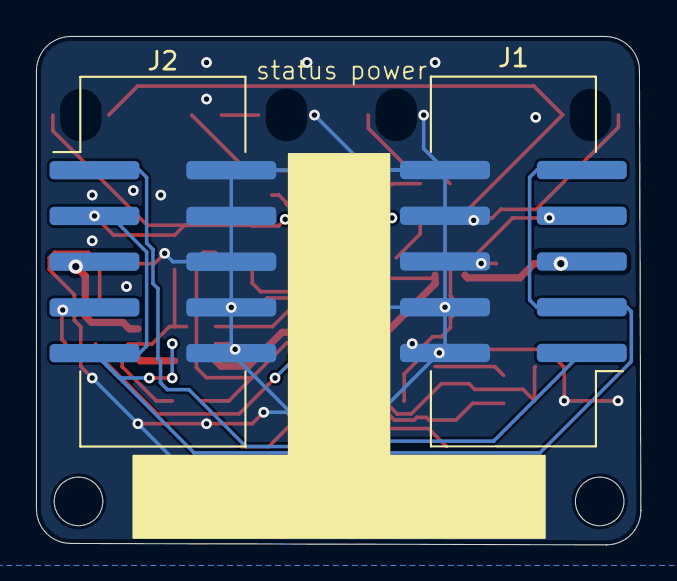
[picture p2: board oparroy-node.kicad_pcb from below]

Board: 2 copper layers, 33.6 x 28.2 mm, 35 parts (2 on the bottom side), 26 nets.

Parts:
C1: 100n; C_0603_1608Metric
C2: 10u; C_0603_1608Metric
C3: 22n; C_0603_1608Metric
C4: 10n; C_0603_1608Metric
D1, D2, D3, D4: UDD32C03L01; D_SOD-323
D5: BAT54S; SOT-23
J1, J2: Conn_02x05_Odd_Even; IDC-Header_2x05_P2.54mm_Vertical_SMD
LED1, LED3: XL-3216SYGC-FB; LED_1206_3216Metric_ReverseMount_Hole1.5x2.4mm
LED2: XL-3216SURC-FB; LED_1206_3216Metric_ReverseMount_Hole1.5x2.4mm
LED4: XL-3216UYC-FB; LED_1206_3216Metric_ReverseMount_Hole1.5x2.4mm
R1, R2, R3, R4, R10: 470; R_0603_1608Metric
R5: DNP; R_0603_1608Metric
R6: 0R; R_0603_1608Metric
R7, R8: 10k; R_0603_1608Metric
R9, R11: 1k; R_0603_1608Metric
R12: 47k; R_0603_1608Metric
R13: 220; R_0603_1608Metric
TP1: SWIO; TestPoint_Pad_1.5x1.5mm
TP2: 3V3; TestPoint_Pad_1.5x1.5mm
TP3: GND; TestPoint_Pad_1.5x1.5mm
TP4: PC7; TestPoint_Pad_1.5x1.5mm
U1: DNP; SOT-23-5
U2: SN74LVC1G3157; SOT-23-6
U3: CH32V003F4P6; TSSOP-20_4.4x6.5mm_P0.65mm

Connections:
3V3: C1.1, C2.1, J1.3, J1.9, J2.3, J2.9, LED1.2, R7.1, R9.1, TP2.1, U1.5, U2.5, U3.9
GND: C1.2, C2.2, C4.2, D1.2, D2.2, D3.2, D4.2, D5.1, J1.2, J1.4, J1.6, J1.8, J1.10, J2.2, J2.4, J2.6, J2.8, J2.10, LED2.1, LED3.1, LED4.1, R8.2, R12.2, TP3.1, U1.3, U2.2, U3.7
PHY1/sel_sw: R6.2, U1.4, U2.6
PHY1/txa_sw: R2.1, U2.4
RX_A: D1.1, J1.5, R1.1
RX_B: D3.1, J2.7, R3.1
SL1/led_x: LED1.1, LED3.2, R10.2
SL1/ledw_a: LED4.2, R11.2
SL1/pwr_led: LED2.2, R9.2
TX_A: D2.1, J2.5, R2.2
TX_B: D4.1, J1.7, R4.2
UNREG: J1.1, J2.1
WD1/kap: C3.1, R13.2
WD1/x: C3.2, D5.3
ka: R13.1, U3.20
led_seg: R10.1, U3.10
led_work: R11.1, U3.8
opa_n: R7.2, R8.1, U3.5
opa_p: R1.2, R5.2, U2.3, U3.6
opa_p_b: R3.2, U3.4
opo: R5.1, U3.1
pc7: TP4.1, U3.17
sel: C4.1, D5.2, R6.1, R12.1, U1.2, U3.12
swio: TP1.1, U3.18
txa_drv: U2.1, U3.19
txb_drv: R4.1, U3.13

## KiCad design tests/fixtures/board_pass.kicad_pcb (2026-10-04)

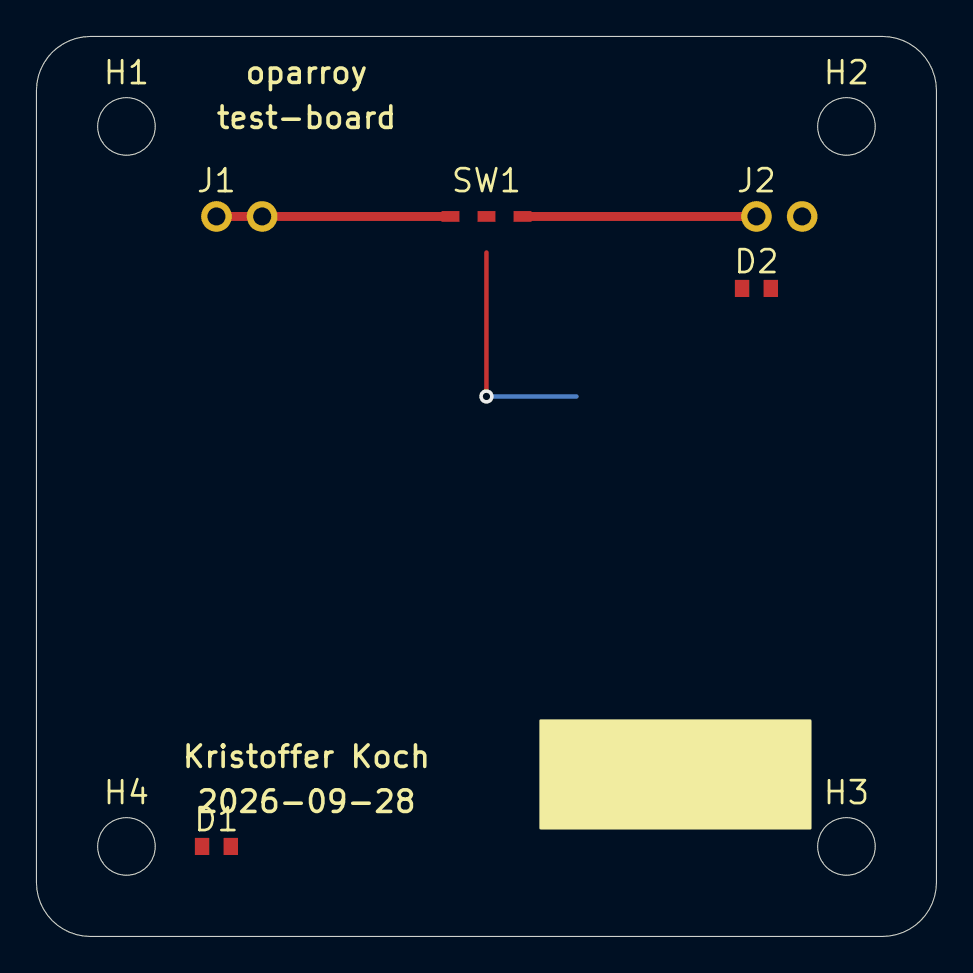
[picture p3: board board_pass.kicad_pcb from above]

Board: 2 copper layers, 50.0 x 50.0 mm, 9 parts (0 on the bottom side), 3 nets.

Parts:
D1, D2: LED; LED_0603
H1, H2, H3, H4: MountingHole; MountingHole_3.2mm_M3
J1, J2: CONN6; CONN_1x06
SW1: SN74LVC1G3157; SPDT

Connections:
BYPASS: J1.1, J2.1, SW1.1, SW1.2
GND: D1.1, D2.1, J1.2, J2.2
SIG: D1.2, D2.2, SW1.3

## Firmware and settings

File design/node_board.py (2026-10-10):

"""The node board constraint skeleton: stackup, net classes, DRC minimums.

One :class:`PcbSpec` is the seed pcbnew opens: :func:`spec` pins the
settled 2-layer 0.8 mm stackup (docs/node-board.md, item 1
— 35 µm copper around a ~0.71 mm FR4 core, ENIG; JLCPCB's exact
thickness offerings verify at quote time), two net classes, and the
fab-floor minimums. ``main()`` writes the pair KiCad consumes:

    boards/node/oparroy-node.kicad_pcb   (stackup + net list)
    boards/node/oparroy-node.kicad_pro   (net classes, board minimums)

**Net classes.** ``Default`` is the implicit catch-all — KiCad puts
every unassigned net in it, so it declares no nets here. ``Bypass``
carries the §4 bypass-path copper: the three nets from J1's ring-A pin
to J2's through the relaxed switch — ``RX_A`` (J1.5 through TVS Dar to
series R Rar), ``PHY1/txa_sw`` (SW1.COM to series R Rat, flattened
name in the board netlist), ``TX_A`` (Rat to
J2.5 through TVS Dat). The class is wider than Default not for current
(the 470 Ω series resistors cap it at mA) but for robustness: this is
the one copper path the ring depends on when the node is dead. The
listen-only RX tap ``opa_p`` (Rar to SW1.B1, the net the MCU sits on)
stays Default: the class's 0.3 mm clearance is unmeetable
inside the MCU's TSSOP-20 footprint, whose 0.25 mm pad gap is fixed —
and the tap is a sense stub off the path, not the path itself. Ring B
has no bypass switch (§3) and stays Default. The clearance sits at
0.3 mm — comfortable on a board this sparse, and above a KiCad 10.0.6
reporting quirk: DRC enforces any class clearance,
but the violation text only cites the class name when the clearance
exceeds 0.25 mm; below that the same violation reports with an empty
constraint name.

``Power`` carries the §2.1 rails: UNREG (the 5-18 V payload rail —
pure pass-through between the two segment connectors on this board,
§2.1: node power never touches it) and 3V3 (the ring power rail, which
a node also feeds through to downstream nodes). 0.5 mm traces are
≈1.6 A at 10 °C rise on 1 oz (IPC-2221) — past the 28 AWG ribbon
conductor's ampacity, so the board is never the power bottleneck; the
0.3 mm clearance matches Bypass, comfortable against UNREG's 18 V
ceiling. GND stays Default: it is poured, not routed. Rail stubs into
pads (the MCU's VDD, a buck's input) neck down manually — class width
is a default, not a rule.

**Board minimums.** Conservative JLCPCB 2-layer numbers, pending the
fab quote (the parts-DB stock checks ride the same quote): JLCPCB
guarantees 0.09 mm trace/space and 0.45/0.2 mm vias on 1 oz; the
minimums here round to 0.1 mm with 0.2 mm holes and 0.3 mm copper-to-
edge (router-bit clearance), deliberately tighter than nothing we
intend to draw so a DRC flag means "fix the layout", never "fight the
fab". The hole-clearance floor sits at 0.15 mm (decided
with the first DRC pass over real layout): the reverse-mount status
LEDs sit over their routed light-pipe NPTHs (the §7 part-over-hole
contract) and KiCad's 0.25 mm default flagged the intent itself;
0.15 keeps the floor below the deliberate geometry while still
catching accidents. The pad-to-slot gap is footprint-fixed, and the
stock footprint's 0.175 mm also lost to the 0.3 mm copper-to-edge
floor (KiCad judges routed NPTH walls like board edges) — settled
in the footprint's favor, not the rule's: the project-local
``Oparroy:LED_1206_3216Metric_ReverseMount_Hole1.5x2.4mm`` narrows
the slot to 1.5 x 2.4 mm for a 0.325 mm nominal gap, still wider than
the LED's 1.2 mm lens. JLCPCB's NPTH-to-copper capability verifies
at quote time. Tune here when the quote lands — nowhere else.

Usage (in the nix dev shell):

    python -m design.node_board               # write boards/node/ artifacts
    python -m design.node_board /tmp/skel     # stage elsewhere
    python -m design.node_board --apply DIR   # merge settings into DIR's board

The plain modes stay the pure emitter — a seed, not a merge: running
them against ``boards/node/`` overwrites the live board. ``--apply``
emits the skeleton to a staging directory and merges it into DIR's
board in process through KiCad's own pcbnew API
(:mod:`oparroy.dsl.pcb_merge`; the dev shell puts nixpkgs' pcbnew on
``PYTHONPATH``, and the project pins the same Python 3.14 it is built
for). Scripted, replacing the manual Board Setup → Import
Settings from Another Board step.
"""

from __future__ import annotations

import argparse
import importlib.util
import sys
from pathlib import Path
from tempfile import TemporaryDirectory

from oparroy.dsl import (
    BoardMinimums,
    NetClassSpec,
    PcbSpec,
    StackupLayer,
    emit_pcb,
    emit_project,
)
from oparroy.dsl.pcb_merge import PcbMergeError, merge_settings

_OUT_DIR = Path(__file__).parent.parent / "boards" / "node"


def spec() -> PcbSpec:
    """Build the node board's constraint skeleton."""
    return PcbSpec(
        name="oparroy-node",
        thickness_mm=0.8,
        stackup=(
            StackupLayer("F.SilkS", "Top Silk Screen"),
            StackupLayer("F.Paste", "Top Solder Paste"),
            StackupLayer("F.Mask", "Top Solder Mask", thickness_mm=0.01),
            StackupLayer("F.Cu", "copper", thickness_mm=0.035),
            StackupLayer(
                "dielectric 1",
                "core",
                thickness_mm=0.71,
                material="FR4",
                epsilon_r=4.5,
                loss_tangent=0.02,
            ),
            StackupLayer("B.Cu", "copper", thickness_mm=0.035),
            StackupLayer("B.Mask", "Bottom Solder Mask", thickness_mm=0.01),
            StackupLayer("B.Paste", "Bottom Solder Paste"),
            StackupLayer("B.SilkS", "Bottom Silk Screen"),
        ),
        copper_finish="ENIG",
        net_classes=(
            NetClassSpec(
                name="Default",
                clearance_mm=0.15,
                trace_width_mm=0.2,
                via_dia_mm=0.6,
                via_drill_mm=0.3,
                nets=(),
                description="implicit catch-all — every unassigned net",
            ),
            NetClassSpec(
                name="Bypass",
                clearance_mm=0.3,
                trace_width_mm=0.4,
                via_dia_mm=0.8,
                via_drill_mm=0.4,
                nets=("RX_A", "TX_A", "PHY1/txa_sw"),
                description="§4 bypass-path copper — no firmware in this path",
            ),
            NetClassSpec(
                name="Power",
                clearance_mm=0.3,
                trace_width_mm=0.5,
                via_dia_mm=0.8,
                via_drill_mm=0.4,
                nets=("3V3", "UNREG"),
                description="§2.1 rails — 3V3 ring power + UNREG payload pass-through",
            ),
        ),
        minimums=BoardMinimums(
            min_clearance=0.1,
            min_track_width=0.1,
            min_via_diameter=0.45,
            min_through_hole_diameter=0.2,
            min_copper_edge_clearance=0.3,
            min_hole_clearance=0.15,
            solder_mask_clearance=0.05,
            solder_mask_min_width=0.1,
        ),
    )


def main() -> None:
    """Emit the skeleton, or emit-and-merge it into a live board (--apply)."""
    parser = argparse.ArgumentParser(description=__doc__)
    parser.add_argument(
        "out_dir",
        nargs="?",
        type=Path,
        help="output directory (default: boards/node/)",
    )
    parser.add_argument(
        "--apply",
        metavar="DIR",
        type=Path,
        help="merge the skeleton's settings into DIR's live board via pcbnew",
    )
    args = parser.parse_args()
    if args.apply is not None:
        if args.out_dir is not None:
            parser.error("--apply takes no positional out_dir")
        _apply(args.apply)
        return
    _emit(args.out_dir or _OUT_DIR)


def _emit(out_dir: Path) -> None:
    """Write the skeleton pair (byte-identical per spec) to OUT_DIR."""
    board_spec = spec()
    out_dir.mkdir(parents=True, exist_ok=True)
    for name, content in [
        ("oparroy-node.kicad_pcb", emit_pcb(board_spec)),
        ("oparroy-node.kicad_pro", emit_project(board_spec)),
    ]:
        path = out_dir / name
        path.write_text(content, encoding="utf-8")
        sys.stdout.write(f"wrote {path}\n")


def _apply(live_dir: Path) -> None:
    """Emit to a staging directory and merge into LIVE_DIR via pcbnew."""
    if importlib.util.find_spec("pcbnew") is None:
        sys.stderr.write("pcbnew not importable — run inside the nix dev shell\n")
        raise SystemExit(2)
    with TemporaryDirectory() as staging:
        _emit(Path(staging))
        try:
            report = merge_settings(Path(staging), live_dir)
        except PcbMergeError as error:
            sys.stderr.write(f"pcb_merge: {error}\n")
            raise SystemExit(2) from None
    sys.stdout.write(
        f"merged {report.staged_pcb} → {report.live_pcb}:"
        f" net classes {', '.join(report.net_classes) or '(none)'},"
        f" stackup {'applied' if report.stackup else 'absent'},"
        f" board minimums {'applied' if report.minimums else 'absent'}\n"
    )


if __name__ == "__main__":
    main()

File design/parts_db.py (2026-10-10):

"""The oparroy parts table: the assembler-inventory view (DESIGN.md §6).

One record per part the captures and benches use, seeded from the
pcba-research inventory snapshot (docs/pcba-research.md) and the
datasheet notes. Every stock number is a *snapshot*: it carries its
as-of date and source, and nothing here is live data — re-query
JLCPCB before ordering. ``check_stock`` flags what has gone stale or
was never queried. Footprint areas are nominal body rectangles, the
currency of the area-bound filter knobs.

Shared part bins are bound here (``R0603``/``C0603``) so captures draw
them from the table; part-specific bindings happen at the capture
site (``design/watchdog_chargepump.py`` binds its BAT54S).

    python -m design.parts_db    # the stock-freshness report
"""

import sys
from datetime import date

from oparroy.dsl import (
    Capacitor,
    PartRecord,
    PartsDb,
    Residuals,
    Resistor,
    SpiceModel,
    Stock,
    Tier,
)

#: The pcba-research inventory snapshot date
#: (docs/pcba-research.md).
_SNAPSHOT = date(2026, 9, 26)

PARTS = PartsDb(
    [
        PartRecord(
            name="r-0603",
            kind="resistor",
            symbol="Device:R",
            footprint="Resistor_SMD:R_0603_1608Metric",
            tier=Tier.BASIC,
            area_mm2=1.28,
            note="generic 0603 Basic bin; per-value LCSC resolves at quote time",
        ),
        PartRecord(
            name="c-0603",
            kind="capacitor",
            symbol="Device:C",
            footprint="Capacitor_SMD:C_0603_1608Metric",
            tier=Tier.BASIC,
            area_mm2=1.28,
            note="generic 0603 Basic bin; per-value LCSC resolves at quote time",
        ),
        PartRecord(
            name="bat54s",
            kind="diode",
            lcsc="C369929",
            symbol="Diode:BAT54S",
            footprint="Package_TO_SOT_SMD:SOT-23",
            value="BAT54S",
            tier=Tier.EXTENDED,
            stock=Stock(
                1_181,
                date(2026, 10, 4),
                "jlcpcb.com product page, human-verified",
            ),
            area_mm2=3.77,
            datasheet="datasheets/BAT54S",
            note=(
                "KEXIN C369929, $0.0158 @1 — verified on jlcpcb.com, "
                "replacing the never-queried TWGMC C727126 "
                "listing; same industry-standard series pair (30 V, "
                "200 mA, SOT-23), so datasheets/BAT54S (the TWGMC doc) "
                "still stands. Extended tier — the ~$3/line fee (§6) "
                "applies; a Basic-tier BAT54S was not found but also "
                "not hunted. Spice model is inline in "
                "circuits/watchdog-chargepump/ until the DSL bench "
                "port retires the hand-written netlists"
            ),
        ),
        PartRecord(
            name="tvs-sod323",
            kind="diode",
            lcsc="C78439",
            symbol="Device:D_TVS",
            footprint="Diode_SMD:D_SOD-323",
            tier=Tier.EXTENDED,
            stock=Stock(
                183_717,
                date(2026, 9, 30),
                "jlcsearch mirror 183,717 / LCSC product page 931,760",
            ),
            value="UDD32C03L01",
            area_mm2=2.52,
            note=(
                "Brightking UDD32C03L01, bidirectional SOD-323 — the §7 "
                "terminal-protection TVS: VRWM 3.3 V, "
                "VBR 4 V min @ 1 mA, VCL 7 V @ 1 A (15 V @ 5 A), Cj "
                "0.8 pF typ — RC ≈ 0.4 ns against the 470 Ω series R, "
                "far inside the §2 decode margin; IR ≤ 5 µA @ 3.3 V; "
                "~$0.037 @1; one BOM line, four positions per node. "
                "Extended tier — no Basic SOD-323 TVS exists (only "
                "1N4148WS-class switching diodes). Rejected: MDD SD03C "
                "(C502532 — the datasheet says 450 pF max vs the "
                "listing's 40 pF claim; 450 pF against 470 Ω is τ ≈ "
                "210 ns, blowing the §2 decode margin), UMW PESD3V3L1BA "
                "(C2687129 — ~100 pF, clamps at 24 V, weakest "
                "electrically), TECH PUBLIC BV03C (C2858699 — ~1 pF but "
                "the datasheet is image-only, unverifiable)"
            ),
        ),
        PartRecord(
            name="sn74lvc1g3157-ti",
            kind="analog-switch",
            lcsc="C10426",
            tier=Tier.EXTENDED,
            stock=Stock(
                51_000,
                _SNAPSHOT,
                "jlcsearch mirror (datasheets/SN74LVC1G3157/notes/facts.md); "
                "unverified at jlcpcb.com",
            ),
            symbol="74xGxx:74LVC1G3157",
            footprint="Package_TO_SOT_SMD:SOT-23-6",
            value="74LVC1G3157",
            area_mm2=4.64,
            spice=SpiceModel("circuits/lib/sn74lvc1g3157.spi", subckt="sn74lvc1g3157"),
            datasheet="datasheets/SN74LVC1G3157",
            residuals=Residuals(
                on_resistance_ohm=25.0,
                on_capacitance_pf=17.3,
                off_capacitance_pf=5.2,
                leakage_ua=1.0,
            ),
            note=(
                "Residuals (SCES424O §5.5): Ron ≤ 25 Ω over the full "
                "signal range (7 Ω typ / 9 Ω max at 3 V, 25 °C); "
                "Cio(on) 17.3 pF, Cio(off) 5.2 pF; leakage ±1 µA max."
            ),
        ),
        PartRecord(
            name="sn74lvc1g3157-umw",
            kind="analog-switch",
            lcsc="C3040658",
            tier=Tier.EXTENDED,
            stock=Stock(
                124_000,
                _SNAPSHOT,
                "jlcsearch mirror (datasheets/SN74LVC1G3157/notes/facts.md); "
                "unverified at jlcpcb.com",
            ),
            symbol="74xGxx:74LVC1G3157",
            footprint="Package_TO_SOT_SMD:SOT-23-6",
            value="74LVC1G3157",
            area_mm2=4.64,
            spice=SpiceModel("circuits/lib/sn74lvc1g3157.spi", subckt="sn74lvc1g3157"),
            datasheet="datasheets/SN74LVC1G3157",
            residuals=Residuals(
                on_resistance_ohm=25.0,
                on_capacitance_pf=17.3,
                off_capacitance_pf=5.2,
                leakage_ua=1.0,
            ),
            note=(
                "UMW clone of the TI part ($0.047 vs $0.072, facts.md); "
                "residuals as the TI part (SCES424O §5.5)."
            ),
        ),
        PartRecord(
            name="ch32v003f4p6",
            kind="mcu",
            lcsc="C5187096",
            tier=Tier.EXTENDED,
            stock=Stock(
                9_000,
                _SNAPSHOT,
                "docs/pcba-research.md; unverified at jlcpcb.com",
            ),
            symbol="MCU_WCH_RiscV:CH32V003FxPx",
            footprint="Package_SO:TSSOP-20_4.4x6.5mm_P0.65mm",
            value="CH32V003F4P6",
            area_mm2=28.6,
            spice=SpiceModel("circuits/lib/ch32v003.spi"),
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

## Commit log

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2026-09-26 DESIGN: layout property checking, board-level checklist; KANBAN: T19
    - DESIGN.md §7: DSL audits physical layout (.kicad_pcb parsing) —
    bypass-path copper independence, placement/mechanical contracts,
    net-class and trace-length checks; constraints also pushed into
    KiCad as net classes/keepouts
    - DESIGN.md §7: board-level checklist (power LED, eFuse/crowbar
    protection subcircuit with sim unit tests, rounded corners,
    standoff holes), with the per-node cost tension flagged
    - DESIGN.md §8: verification layers now span schematic and layout
    - KANBAN.md: new card T19 (layout property checker, gates T10);
    T10's Blocked-by corrected to include T17
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2026-09-28 dsl: typed jellybean parts — Resistor/Capacitor/Bat54s, construction is the wiring
    DESIGN.md §7 (2026-09-27 decisions): pin names are keyword-only class
    signature parameters, so the type checker and autocomplete cover
    declaration and connection alike; value positional only for
    unpolarized R/C; footprints default per class (subclass per bin —
    R0603/C0603 in the capture), overridable per instance. Circuit.part
    accepts a typed spec and wires at placement, atomically (every net
    resolved before anything is placed). The watchdog capture migrates to
    typed parts; the golden netlist is byte-identical. BAT54S stays
    package-as-one-part, matching KiCad's own single-unit modeling.
    ty uses its own s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
    [ir.py, parts.py, test_dsl_parts.py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]
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2026-09-28 T7ba: DSL subcircuit composition — ports, instances, flattening pass
    Subcircuits are instanced units with declared port interfaces (§7):
    Circuit.port marks an external-facing net, Circuit.instance captures a
    Subcircuit per instance and binds every port by keyword, and
    Circuit.flatten is the pass that reduces the hierarchy to the flat IR
    checks and emitters consume. Instance names prefix part refs and
    internal nets (WD1/Rs, WD1/x) — refdes stability across source edits —
    while port nets merge into the bound parent net. Hierarchy survives as
    metadata: Part.path feeds real sheetpaths in the KiCad netlist with
    content-derived tstamps (the channelization hook). check/emit/dot
    flatten impli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
    [check.py, dot.py, ir.py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]
2026-09-28 T7bb: DSL port arrays and bundles — §3 connector block
    Port arrays (Circuit.port_array): width-fixed port vectors bound
    element-wise at instantiation; width mismatch raises at capture.
    Bundles (Circuit.bundle): named groups aliasing existing nets — the
    §3 connector pinout as one connectable unit. Members name wires, not
    node functions, so two segment faces join member-to-member; power nets
    alias into both faces' bundles, and a port reached through two groups
    must resolve to one parent net.
    BundleConnector (parts.py): the connector block — bundle member to pin
    number(s) mapping as class data; pin_map values widen to tuples for
    multi-pin members (the paired §3 grounds). design/segme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
    [check.py, ir.py, parts.py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]
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2026-09-28 dsl: port limit ranges, interval-containment check, waivers as data (T8)
    Typed ports carry voltage/current-limit ranges (Interval, Limits on
    Circuit.port); the validation pass checks interval containment at
    instance bindings — a sink's acceptable range must cover the connected
    source's output range, so tolerance stackup becomes checkable data.
    Waivers are explicit, path-addressed capture data (Circuit.waive with a
    mandatory reason): a waived error degrades to a WAIVED finding, a stale
    waiver warns. Red/green-verified with deliberate mutations.
    [check.py, ir.py]
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2026-09-28 dsl: parts DB — records, constraint-filtered selection, stock audit (T7c)
    One PartRecord per part: LCSC number, JLCPCB Basic/Extended tier, a
    stock snapshot with as-of date and source, the KiCad
    symbol/footprint pair, the spice model binding, and the datasheet
    pointer (DESIGN.md §6 inventory-driven selection).
    Selection is constraint filtering over the table, not lookup:
    PartFilter is refinement data (kind, tier, area bounds, allowed
    footprints, exclusions, a required part, an in-stock constraint)
    composing conjunctively; resolve() demands exactly one match.
    PartsDb.bind turns a record into a typed part class so captures draw
    their bins from the table. check_stock is the freshness audit: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
    [parts_db.py, test_dsl_parts_db.py]
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2026-09-28 T7d: DSL ngspice emitter — DUT .subckt backend, bench-compatible
    emit_spice renders the flat IR as a .subckt with ports in declaration
    order, so a capture matching a hand-written circuits/ interface drops
    into the existing bench decks unmodified — stimulus and .meas stay in
    the benches, the DSL emits the circuit. Spice bindings are ad hoc
    until T7c: a symbol-keyed table (R/C two-pin primitives, BAT54S
    series-pair expansion) plus caller-passed .model definitions, a part's
    value naming its model. Byte-identical emission; hierarchy flattens
    implicitly (ngspice accepts '/' in names verbatim).
    design/watchdog_chargepump.py --spice emits the wd_chargepump DUT
    netlist. Acceptance proof: the em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
    [spice_emit.py, watchdog_chargepump.py]
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2026-09-28 T22: reject a stale annotation table against a renamed circuit
    Annotation.circuit was stored and documented as the guard against
    loading a table written for another design ('a visible error, not
    silent misassignment'), but annotate() never compared it — a stale
    --annotation file silently misassigned refdes. Now it raises.
    Red/green: test_stale_circuit_name_rejected failed before the check.
    [annotate.py, test_dsl_annotate.py]
2026-09-28 T19: .kicad_pcb parser, layout property checker, constraint emitter
    kicad_pcb.py parses a .kicad_pcb (same s-expression dialect as the
    libraries, sexpr is the reader) into a tolerant typed board model:
    stackup, net classes, footprints/pads, copper segments/vias, outline
    edges/arcs, silkscreen texts/rects, zones with keepouts.
    layout_check.py asserts the §7 layout contract: one LayoutRules value,
    check_layout reporting batched Issues like the schematic pass —
    copper-layer count and thickness, net-class width/via compliance,
    per-net trace-length budgets (feeds T15), min corner radius with a
    collinear-junction exemption, required silkscreen board-ID fields,
    serial-box area, mounting-hole co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
    [board_pass.kicad_pcb]
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2026-09-28 T19 fixup: count power/mixed inner layers as copper, PcbError on bad net codes
    Review found the layer parser only counted kind==signal, so a 4-layer
    stackup with KiCad power-plane (power) or mixed inner layers undercounted
    copper and failed the stackup contract wrongly; and a malformed net code
    escaped as a bare ValueError instead of PcbError, unlike every other
    number read. Also documents that Pad.at is footprint-local and footprint
    rotation is not modeled — the remaining serial-box clearance check needs
    to know that.
    [kicad_pcb.py, test_dsl_pcb.py]
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2026-09-28 dsl: close sibling port-to-port containment gap, collect subcircuit waivers (T8)
    Review fixups on the T8 slice:
    - The containment check compared ports only against the parent net's
    own declared ranges, so one instance's 0..5 V output port wired
    straight into a sibling's 0..3.6 V input port over a plain net —
    the common board-level case — produced no finding. The check now
    groups endpoints per net and checks every declared sink against
    every declared source on it.
    - Waivers declared inside a subcircuit were silently ignored (no
    WAIVED finding, no stale warning). Waivers are now collected
    recursively, with instance paths prefixed, so a waiver lives next
    to the wiring it ex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
    [check.py, ir.py]
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2026-09-28 T9: DSL pin maps — request/bind model, chip tables, budget check, header emitter
    Pins are requested by function (gpio.request("keepalive")), pads bind
    late as refinement data (gpio.bind(...)), and the one authoritative
    table feeds both consumers: emit_pin_header (freestanding-C++ header —
    constexpr pads plus peripheral-channel constants, code-std.md §7
    style) and check_pin_map (the §5 GPIO-budget check: pad fit against
    the datasheet-derived chip table, one function per pad, reservations
    honored, total count inside the chip's GPIO count).
    The CH32V003F4P6 chip table covers the default alternates (DS0 §2.1,
    datasheets/CH32V003/notes/gpio-pinout.md); AFIO remaps are refinement
    room. Emi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
    [pinmap.py, test_dsl_pinmap.py]
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2026-09-28 T21: fixups from review — grandalf has no orthogonal router, note its GPLv2|EPLv1 license, cite SKiDL generate_svg skin prior art, point follow-up at T26
    [dot.py]
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2026-09-29 design: settle the segment connector — 2.54 mm 2x5 IDC on 3365/10
    Supersedes the 2026-09-27 6-pin pinout (DESIGN.md §3). Two 10-pin
    2.54 mm 2x5 IDC box headers per node on 10-way 1.27 mm-pitch 28 AWG
    ribbon: the cheapest IDC system by 2-4x ($0.31 of connectors per node
    @100, LCSC C22385222 + C8373, fetched 2026-09-29) and the only one
    with deep stock. The conductor order UNREG,GND,3V3,GND,A,GND,B,GND,
    3V3,GND lands row 2 as a solid ground row, ground-flanks every
    conductor (the G-S-G condition the reach model assumes), and doubles
    3V3 — the broken-loop power budget stretches 5.8 m to ~12 m at 10 mA
    nodes, clearing the 10 m signal reach.
    Assembly split: JLCPCB places only the front —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
    [parts_db.py, segment.py, test_dsl_bundles.py]
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2026-09-29 design: status LEDs go reverse-mount, shining through PCB holes
    The §4.1 status row moves to 1206 reverse-mount LEDs on the front —
    pads on the single-sided assembly face, lens emitting through a
    routed board hole to the back, the connector side where a viewer
    stands (2026-09-29, DESIGN.md §4.1). The back's copper set stays
    exactly the two segment connectors and the front stays flat against
    the enclosure wall; the enclosure owes nothing. One XINGLIGHT
    XL-3216-FB series covers all four positions (~$0.05/node, Extended);
    the working LED is the 570 nm yellow-green because the series' 525 nm
    true green has Vf 3.4 V, undrivable from a 3.3 V GPIO. Parts DB gains
    the three color records; the §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
    [bins.py, node.py, parts_db.py]
2026-09-29 design: node capture binds MCU pads from the pin table
    Found by an I/O-budget review (2026-09-29): design/node.py hardcoded
    keepalive on PC4 and the status LEDs on PC7/PC5/PC6, while the
    authoritative pin table (design/node_pins.py) binds keepalive=PD3,
    leds=PD0/PC0/PC1, and PC4/PC5/PC6 to the buzzer/button payload
    superset. Fabbed as-is, firmware built on pins.hpp would strobe a pad
    the charge pump doesn't listen to (permanent bypass) and drive LEDs
    that aren't there. The capture now binds its MCU pads from
    capture().assignments — one pad table, no drift surface. DESIGN.md §7
    records the incident.
    [node.py]
2026-09-29 design: node programming flow — SWIO pogo strip, programmer powers the board
    Records the production-programming decision (DESIGN.md §6,
    2026-09-29): nodes flash post-SMT over SWIO on a pogo jig — the
    CH32V003 has no factory bootloader, PD1 is the only way in — with a
    WCH-LinkE driving 3V3 + GND + SWIO. The programmer powers the board:
    brick recovery is a power cycle through reset (quirks.md §Debug), so
    the jig's 3V3 never comes from the ring. Positional addressing means
    zero per-node provisioning: one image, personality type byte where
    needed, factory UNIID logged against the handwritten unit serial.
    The node capture gains the TP1/TP2/TP3 (SWIO/3V3/GND) pad strip;
    the §7 checklist g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
    [node.py]
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2026-10-04 dsl: KiCad-10 constraint skeleton — stackup in .kicad_pcb, net classes + board minimums in .kicad_pro
    KiCad 10 rejects net_class in .kicad_pcb setup, so the emitter splits:
    stackup and the net list land in the emitted .kicad_pcb, net classes
    and board minimums in the .kicad_pro (KiCad 10.0.6 quirk: DRC
    enforces any class clearance, but the violation text only cites the
    class name above 0.25 mm). DRC enforcement verified headless — no GUI
    step (DESIGN.md §7).
    [board_pass.kicad_pcb]
2026-10-04 design: node-board decisions settled and landed in capture
    The 2026-09-29 decision inventory settles same-day
    (docs/node-board-2026-09-29.md): 2-layer 0.8 mm stackup, TVS
    populated (Brightking UDD32C03L01), DNP 74LVC1G17 + fitted 0 ohm
    insurance on sel, per-connector LEDs merged onto one antiparallel
    GPIO (frees PC1), PC7 test pad, pogo strip at 2.54 mm pitch on a
    short edge, connectors on opposite short edges, silkscreen ID on the
    back, third-party population OK, CI board fabs first (assemble 2).
    Capture deltas: the antiparallel LED merge becomes the StatusLeds
    subcircuit with a sim-pinned drive-state contract
    (circuits/status-leds/, tests/test_status_leds.py) — the bench
    re-fails when D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
    [bins.py, node.py, node_pins.py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]
2026-10-04 design: node-board constraint seed, feasibility layout, layout checklist
    design/node_board.py emits the boards/node/ skeleton pair — the
    settled 2-layer 0.8 mm stackup, the Default/Bypass/Power net classes
    (Bypass carries the ring-A dead-node copper wider for robustness, not
    current; Power the 3V3/UNREG rails), and fab-floor minimums tuned so
    a DRC flag means fix the layout, never fight the fab. The emit is a
    seed, not a merge: with layout live in the .kicad_pcb, constraint
    changes re-emit to a staging path and merge via pcbnew's Board Setup
    (§7: lean on KiCad's own code as the merge engine; scripted API
    merge is IDEAS).
    The 2026-10-04 feasibility place-and-route solves the two-layer
    boa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
    [oparroy-node.kicad_pcb]
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2026-10-04 parts: BAT54S verified — KEXIN C369929, Extended, 1181 @ $0.0158
    Human-verified on jlcpcb.com 2026-10-04 (the T22b check): the DB
    binds KEXIN C369929 (SOT-23, Extended tier, 1,181 in stock at
    $0.0158 @1), replacing the never-queried TWGMC C727126 listing. Same
    industry-standard series pair, so datasheets/BAT54S stands. The
    resolved IDEAS bullet leaves IDEAS.md; T22b's remaining items are the
    C22385222 header stock re-check and the fab itself.
    [parts_db.py, test_dsl_parts_db.py]
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2026-10-04 dsl: explicit min_hole_clearance floor; opa_p drops to Default class
    Two constraint decisions from the first DRC pass over real node-board
    layout (2026-10-04):
    - BoardMinimums gains min_hole_clearance, emitted to the project's
    design rules and parsed back. The node board sets it to 0.15 mm:
    KiCad's 0.25 mm default flagged the reverse-mount LEDs' routed
    light-pipe holes (the part-over-hole contract, DESIGN.md section 7)
    whose pad-to-hole gap is footprint-fixed at 0.175 mm. 0.15 keeps the
    floor just below the deliberate minimum while still catching
    accidents; JLCPCB's NPTH-to-copper capability verifies at quote
    time — if the fab floor lands above 0.175 mm, the LED footprint's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
    [kicad_pro.py, node_board.py, pcb_emit.py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]
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2026-10-05 dsl: drive pcbnew's settings import through the KiCad API
    Replaces the manual Board Setup → Import Settings from Another Board
    step with a scripted merge (DESIGN.md §7: lean on KiCad's own code):
    oparroy.dsl.pcb_merge loads the staged skeleton and the live board,
    clones the design settings, and saves — the emit is a seed, not a
    merge, so re-running it against boards/node/ would clobber layout.
    design.node_board --apply DIR wraps it (emit to staging, merge via the
    flake's kicad-python).
    Mechanism verified against KiCad 10.0.6 on 2026-10-04: CloneFrom
    transfers stackup, layers, and board minimums, but re-points the
    design settings' m_NetSettings shared_ptr at the staged project while
    Sav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
    [kicad_pcb.py, kicad_pro.py, node_board.py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]
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2026-10-05 python: harmonize on 3.14 — one interpreter for venv and pcbnew
    Answers the nix/uv version question (#37): nixpkgs' pcbnew is built
    for Python 3.14, and the project now pins the same 3.14
    (.python-version, requires-python, ruff py314, ty) instead of
    scripting KiCad through a separate kicad-python wrapper. uv finds
    nix's own 3.14.7 on PATH inside the dev shell, and the shellHook
    exports pcbnew's site-packages on PYTHONPATH, so `import pcbnew`
    resolves in the project venv (verified against KiCad 10.0.6 on
    2026-10-05: direct import, design.node_board --apply byte-identical
    to the wrapper-driven merge, 380 tests, ruff/ty/pre-commit clean).
    The kicad-python wrapper leaves the flake; pcb_merge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
    [node_board.py, pcb_merge.py]
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2026-10-06 design: status LEDs bind the 1.5x2.4 mm light-pipe footprint
    The stock reverse-mount 1206 footprint's 1.8x2.4 mm NPTH slot sits
    0.175 mm from its own SMD pads, and the board's 0.3 mm copper-to-edge
    floor (JLCPCB router bit) judges routed NPTH walls like board edges —
    8 intrinsic copper_edge_clearance errors. Settled 2026-10-05 in the
    footprint's favor, not the rule's: a project-local Oparroy: variant
    narrows the slot to 1.5x2.4 mm for a 0.325 mm nominal pad-to-slot gap,
    still wider than the LED's 1.2 mm lens. Exact copy of the stock
    footprint otherwise (fresh uuids, same 3D model); the bin, the three
    parts-DB records, and the golden netlist rebind.
    [bins.py, parts_db.py]
2026-10-06 boards: node — LED light-pipe slots shrink to 1.5x2.4 mm
    Rebind LED1-LED4 to Oparroy:LED_1206_3216Metric_ReverseMount_Hole1.5x2.4mm
    and narrow their embedded NPTH pads in place — positions, rotations,
    uuids, tstamps, and pad nets untouched, so the back-annotation join
    keys still hold. Add boards/node/fp-lib-table so pcbnew resolves the
    project library in the GUI. DRC: the 8 LED copper_edge_clearance
    errors are gone; every other violation is byte-identical to the
    pre-change report.
    [oparroy-node.kicad_pcb]
2026-10-06 docs: record the 2026-10-05 LED light-pipe hole decision
    node_board.py's docstring pre-committed to shrinking the hole rather
    than the rule if the fab floor beat 0.175 mm — that is now settled
    (1.5 x 2.4 mm slot, 0.325 mm nominal gap). The layout checklist marks
    the LED NPTH pairs resolved; the node-board card drops the item.
    [node_board.py]
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2026-10-10 dsl: instrumentation transforms — records, scopes, engine, provenance
    Transforms are data: four kinds (insert-series, add-shunt, add-tap,
    substitute) scoped per-tile or per-instance, applied by a new
    transform.py engine to the hierarchical capture between instantiation
    and check. Each matched tile instance flattens in place, its target
    net splits with #a/#b aliases, placeholder nets in part specs rebind,
    and control/source/tap connections escape as new tile ports bound to
    board nets. Every created part and net carries a Provenance(transform,
    base) tag that survives flattening and renaming — the input the
    reset-state equivalence proof consumes.
    ir.py grows the support: Provenance, Placem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
    [check.py, ir.py, transform.py]
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2026-10-10 dsl: reset-state equivalence proof (check_equivalent)
    The second half of the instrumentation memo: check_equivalent(base,
    instrumented, plan) consumes the transform provenance tags and proves
    the instrumented board in reset state reduces to the plain board —
    series elements to wires, shunt branches absent, taps high-impedance,
    the anti-drift bijection over base parts and net memberships — per
    tile, composed upward. Residuals are enumerated as data
    (net, kind, magnitude) and each must carry a budget citation; one
    without is an error. Reset levels are proof inputs (memo Q2), keyed
    like the transform handles; the §8 all-zeros POR invariant is checked,
    never assumed.
    Memo Q3/Q5 settled on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
    [equivalence.py, ir.py, parts.py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]
2026-10-10 dsl: fix equivalence-proof review findings
    Review of the reset-state equivalence proof surfaced three defects:
    - _base_net_names KeyError'd on a port wired straight through to a
    deeper instance (the CI board's own Node-tile shape): bound ports
    were never recorded in the running name map, unlike flatten, which
    keeps them. Record the resolved name under the port's id too.
    - Tapping the side of a split internal net (sense#a) false-positived
    three ways: the tap lookup stripped the # suffix and missed the
    literal binding, and the tap board net's provenance base pointed at
    the cut side rather than the ultimate base-capture net. Look the
    binding up by full name first (the #-strip rem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
    [equivalence.py, test_dsl_equivalence.py, transform.py]
2026-10-10 dsl: name the tile-local net key (TileNet), ban deep type nesting
    The transform Handles and the equivalence proof's tables were keyed by
    bare tuple[tuple[str, ...], str] — a domain concept (tile instance
    path + tile-local net name) wearing structural clothing, transposable
    without a murmur. TileNet (frozen, ordered dataclass in ir.py) is now
    the key shape of Handles, check_equivalent's reset_levels, and the
    proof's internal base-net and tap tables.
    code-std.md §12 gains the rule: name composite types once a signature
    nests past one parameterization — a frozen dataclass when the parts
    have distinct meanings, a type alias for pure container shorthand;
    review owns it since neither ruff no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
    [equivalence.py, ir.py, test_dsl_equivalence.py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]
2026-10-10 docs: drop decision timestamps; git blame is the timeline
    Decisions, changes, and status no longer carry dates in docs or
    comments — provenance lives in git history. AGENTS.md gains the rule
    (with a carve-out for dates that are themselves the fact: price/stock
    snapshots, datasheet revisions, external events), and the datasheets
    section drops the 'dated' requirement for quirks bullets.
    Also renames docs/*-YYYY-MM-DD.md to undated names and strips the
    'settled/decided/landed/raised YYYY-MM-DD' annotations across DESIGN,
    KANBAN, IDEAS, README, code-std*, docs, and code comments.
    [bins.py, dot.py, equivalence.py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]
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2026-10-10 dsl: copper-geometry bypass independence in the layout checker
    The §4 bypass contract gets its second half: no copper primitive on a
    bypass net (segment, arc, via) may touch another net's copper on a
    shared layer. Tracks are capsules, vias circles per layer, arcs
    polygonized into chords at a fixed sagitta; zones and pads stay out of
    scope (a zone's parsed polygon is the outline, not the poured copper;
    pads lack board-absolute positions since footprint rotation is not
    modeled). The parser now reads board-level arc tracks — the shape
    verified against KiCad 10.0.6 — and arcs count toward net-class width
    floors and trace budgets. Calibrated against boards/node/: the bypass
    chain (RX_A, PHY1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
    [kicad_pcb.py, layout_check.py, test_dsl_layout_check.py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]
2026-10-10 dsl: terminal-protection placement contracts in the layout checker
    The DESIGN.md §7 checklist contract — TVS adjacent to its connector,
    series R between TVS and µC pin — as a capture-driven layout check.
    terminal_protection_rules derives one TerminalProtectionRule per
    Device:D_TVS in the capture (exposed net, series R, connector named by
    capture path, refdes resolved through the annotation, so the contract
    survives KiCad's geographic renumbering); check_layout asserts the TVS
    clamps the exposed net within reach of its connector, the R straddles
    the exposed net with nothing else on it, and the R sits near the
    protected-side logic. Calibrated green against the node board's four
    terminal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
    [layout_check.py, test_dsl_layout_check.py]
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
